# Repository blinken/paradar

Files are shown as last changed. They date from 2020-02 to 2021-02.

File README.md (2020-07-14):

# paradar: locates and indicates aircraft around you

<div align="center">
<br/>
<br/>
<br/>
<br/>
<del>£339</del> <b>£299 <a href="https://paradar.co.uk">Click here to buy a paradar!</a> All sales help fund development.</b><br/>
<br/><br/>
</div>

### paradar is a tiny, handheld ADS-B receiver for paramotor, paraglider, drone and general aviation pilots.

 * 36 ultrabright LEDs clearly indicate the direction of other aircraft in a ~20km radius
 * Fully self contained handheld receiver and display - can be used without a linked phone or tablet
 * Much faster to understand at glance vs an app on your phone
 * Optionally feeds high quality GPS and traffic information to SkyDemon or other GDL90-compatible EFB apps
 * Easily readable in full sunlight, on the ground or in the air on your flight deck
 * Receives ADS-B on 1090Mhz (UK/EU) and 978Mhz (US)
 * Colour-blind-friendly colours
 * Built-in 1950mAh battery (2.5 hours battery life) with USB-C fast charge
 * Only 88mm x 88mm and 175g with antenna
 * **Open source hardware and software**

It can be used standalone (with or without a phone or tablet), on the ground as
a handheld compass that indicates air traffic, or in the air on your flight
deck to improve your situational awareness.

Paradar is the result of a short two-week project that grew into a monster. I
fly in a busy area, and I wanted to see aircraft in the sky around me - and
apps designed for fixed-wing pilots are tricky to read while flying
an ultralight. Paradar started out as a Raspberry Pi attached to a USB
software-defined radio dongle, and some LEDs from Amazon. Six months later,
it's now a professionally manufactured PCB and case that fits in the palm of
your hand. The journey to get here was [long and arduous.](#design)

<div align="center">
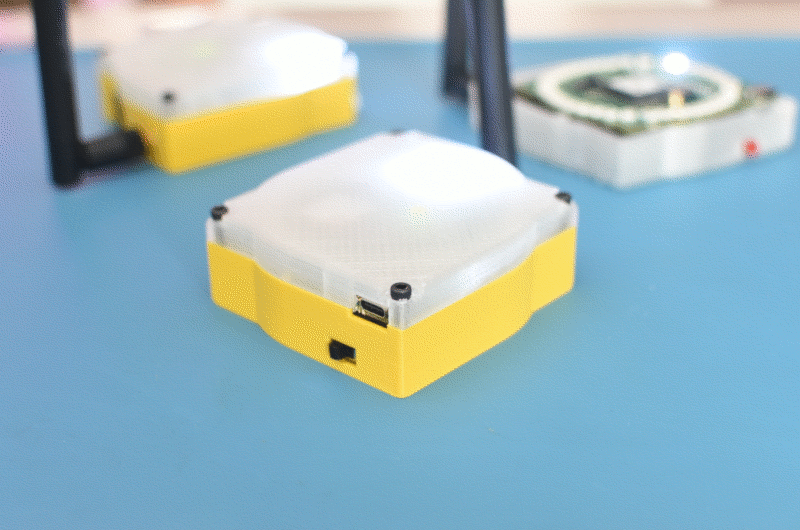
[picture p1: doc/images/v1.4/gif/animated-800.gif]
<br/>
<i>Check out the cool animated GIF I made</i>
</div>

# Project news & roadmap

### Hardware

**2020-05-03** Not too much to report recently: I'm mostly waiting for
manufactured PCBs from PCBWay to arrive. They're making progress, which is
good - but COVID-19 is causing huge delays. Assembled boards should ship soon -
then I get to do a ton of testing!

**2020-03-29** A lot of work this week to finalise assembly, fix bugs after
feedback from the beta testers, and start the process of finding someone I can
outsource the PCB manufacture to. To put together the first few boards I'm
working with [PCBWay](https://www.pcbway.com/pcb-service.html) (click for some
neat videos) in Shenzhen, China, who are a large PCB manufacturer and assembler - alongside
a distributor in the UK to sell and source the devices. It's been a pretty
straightforward experience working with them so far - most of the pain has been
around sourcing parts, but we've settled on a final BOM that they say they can
deliver.

Obviously the massive global disruption from COVID-19 is causing a few
headaches, mostly around shipping and delivery of parts - getting certain
microUSB connectors has been a nightmare. However, the cursed package arrived
this week (the final component I was waiting on) and now it's possible to
assemble the boards together in one unit.

The bottom photo below is of the new optimised assembly. For the beta units, we
soldered wires by hand from the USB port to the Raspberry Pi (top photo) - and now
there's a neat little custom adapter board to do this!

<p align="center">
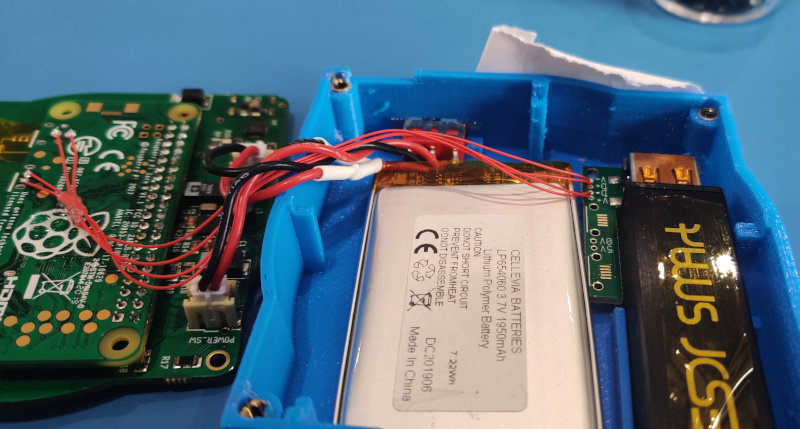
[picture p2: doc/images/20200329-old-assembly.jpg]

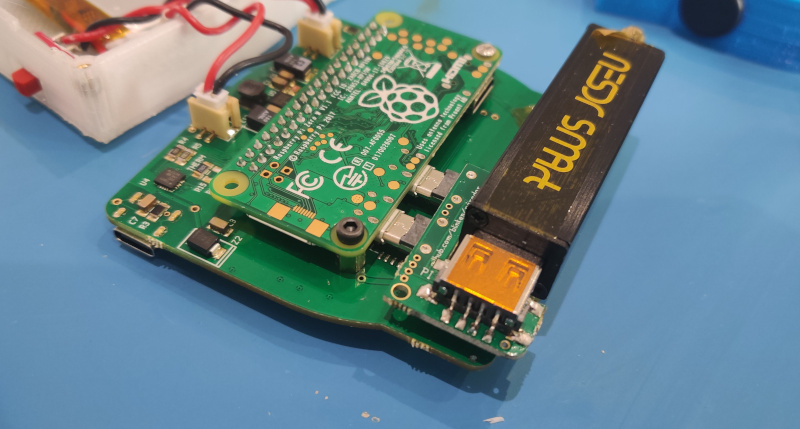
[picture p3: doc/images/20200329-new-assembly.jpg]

</p>

Some other news - paradar branded antennas! 1090Mhz antennas are really hard to
get at a reasonable price outside of a manufacturer - they're fairly specialist -
and manufacturers won't sell you less than a few hundred. So we've found a
factory and ordered a _load_. But as a bonus, they'll engrave a logo!
Behold the new paradar logo and antenna design:

<p align="center">
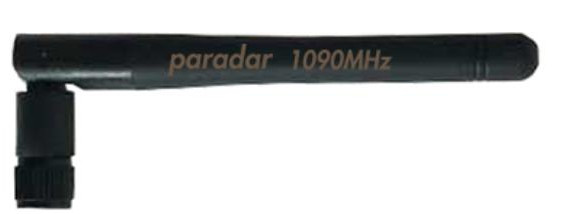
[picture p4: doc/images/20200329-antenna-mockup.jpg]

</p>

**2020-03-24** Coronavirus disruption aside... my [distribution partner](https://paradar.co.uk) in the
UK is shipping the first run of Paradars! I have a small number ready to go,
and enough components to make up a few more around the ongoing supply chain
disruption. Get them while they're hot!

**2020-02-25** DHL confirms that the first run of boards has _arrived in the
UK!_ With luck, they'll be with my distrubution partner by the end of the week.
Assuming there's no unexpected hardware issues, there should then be enough
boards and components to make up the set of 10 units for the beta test group
over the weekend.

Case design has also been ticking along, and my ghetto towel-covered 3D printer
has been working overtime to print up prototypes. So many broken prototypes. 3D
design is hard. The good news is that I've settled on a case that
encapsulates a larger but less-power-hungry SDR, featuring a sturdier SMA
connector. It's a touch larger overall but worth it from a reliability perspective.

<p align="center">
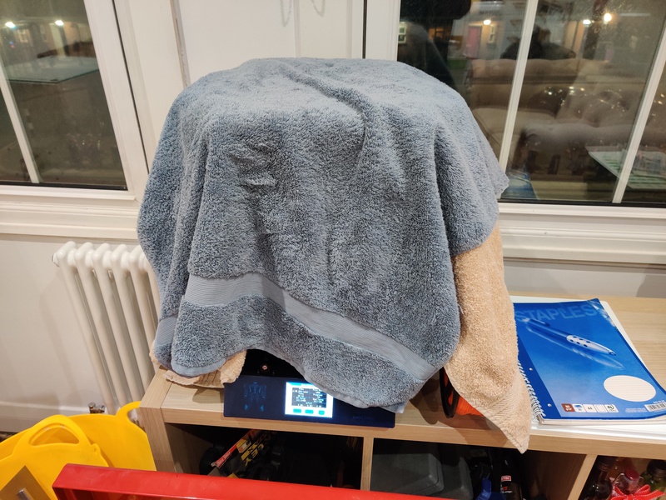
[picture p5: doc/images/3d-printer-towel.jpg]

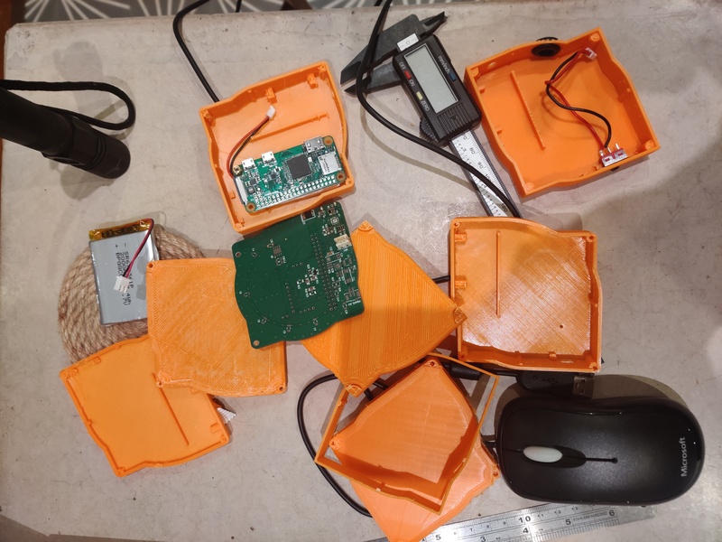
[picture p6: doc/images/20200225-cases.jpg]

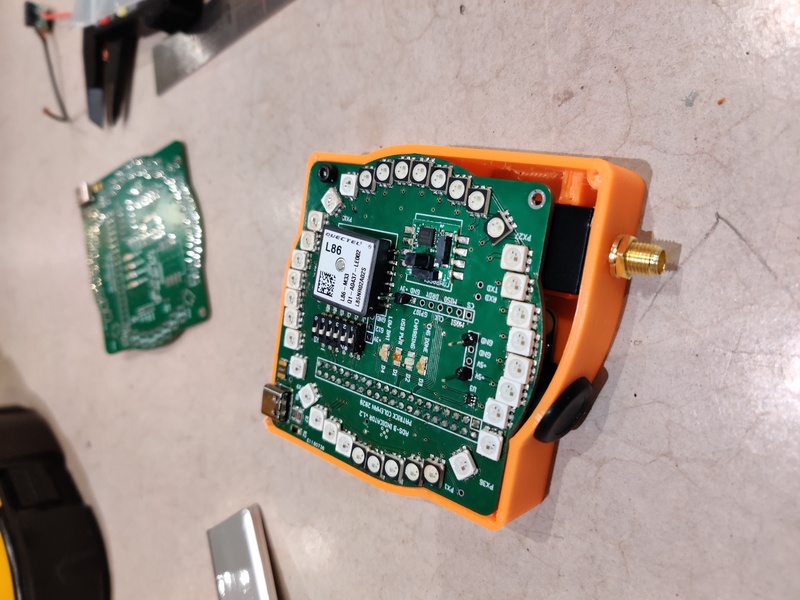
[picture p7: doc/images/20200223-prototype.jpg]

</p>

The next step is to print some cases in transparent ABS to verify the LEDs can
be clearly seen. Not much left to do here!

**2020-02-12** After (too) many iterations, the final, tested PCB layout is
done :tada: :tada: and has been sent for an initial manufacturing run of 40
boards.

The case design is close to complete, but requires some tweaking to add holes
for the SD card and antenna.

### Software

**2020-03-24** Some good bugfixes this week from *loads* of testing.

 * Fix an off-by-one error that meant the 36th LED wasn't getting used
 * Improve compass stability a ton - by adding a moving average over the sensor readings
 * Improve wifi reliability (fix GPIO pullup issues)
 * Improve SkyDemon compatibility - send messages slightly more often

Battery life tests out at 2-2.5 hours without wifi, which is probably as good
as we're going to get without a bigger battery. That SDR is pretty power
hungry.

**2020-03-24** Software is complete and well-tested. Test units have been shipped to a small group of beta testers for their feedback

**2020-02-25** We're just about feature-complete! 978MHz ADS-B is working, LED
colours are now red/green-colourblind-friendly, take-me-home feature is
implemented and working. The user can configure the following features via the
six configuration switches on the top of the board:
 * high_brightness: switch LEDs between medium and high brightness
 * wifi_enabled: enable/disable Wifi AP mode (for SkyDemon) - to be implemented
 * track_home: enable/disable recording GPS location at startup (or when switch is activated), and indicate the direction with a light blue LED.
 * show_north: enable/disable indication of compass north as a white LED on the display
 * led_test: enable/disable test mode, which cycles through red/green/blue/white to help with manufacturing (spotting dead LEDs)
 * enable_978: enable/disable 978MHz reception. The device only has one radio,
   so when this mode is enabled it will listen for about 10 seconds at a time
   on each frequency. Aircraft broadcast their position every 1-2 seconds, so
   there's a low probability that any will be missed. This is only useful in
   the USA, where 978MHz is in use.

The main remaining feature here is GDL90/SkyDemon support and testing. It's
really exciting to be so close to the finish line!

**2020-02-12** The software supports receiving ADS-B on 1090Mhz (EU frequency),
indicating it on the display, and mapping the display to the user's position
using the compass. The following extra features are planned for the initial
release in April/May:

 * WiFi base station and support for SkyDemon via GDL90
 * Support for US ADS-B (978MHz)
 * A ton of Ansible automation to ensure the board runs reliably
	 * Take a Raspbian image and deploy the software to it
	 * Convert an SD card between read-only and read-write mode
	 * Start software on boot
	 * Watchdog to ensure software is running correctly
 * User configuration via the DIP switches on the board
	 * WiFi on/off to save battery
	 * Listen on 1090Mhz, 978Mhz, or both (switch between frequencies periodically)
	 * LED brightness

# Design

<p align="center">
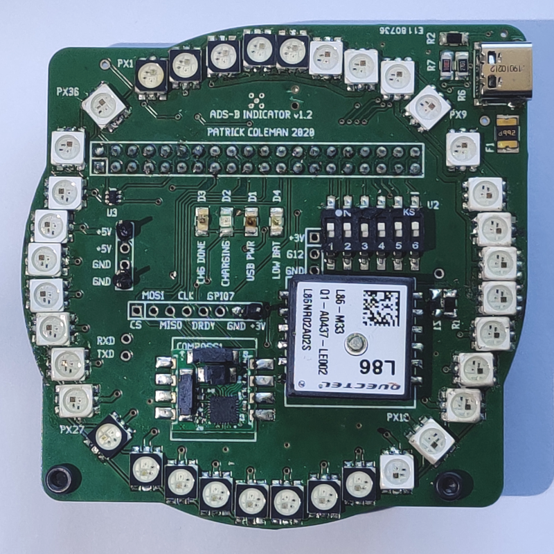
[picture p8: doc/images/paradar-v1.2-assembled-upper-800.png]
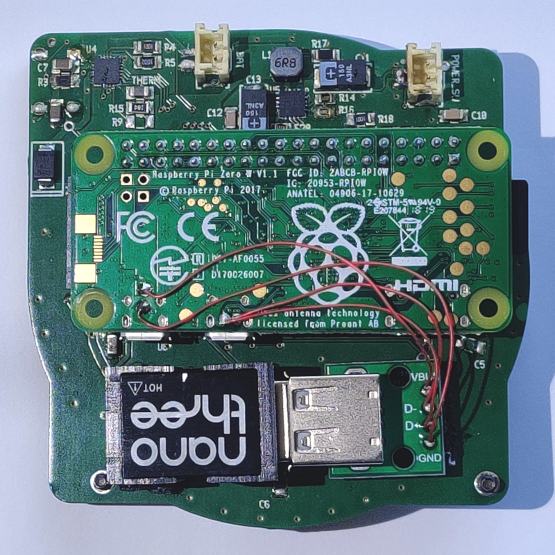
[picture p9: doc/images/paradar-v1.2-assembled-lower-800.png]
 <br/>
<i>Board version v1.2 without the USB right-angle connector</i>
</p>

paradar is built around the Raspberry Pi Zero, a cheap and fast general purpose
embedded computer (1GHz ARM, 512MB RAM) with built-in WiFi. The software runs
on an SD card booting Linux (based on Raspbian), which provides drivers for the
SDR and supporting software.

| Part | Where to buy  |
|:---| ---:|
| Raspberry Pi Zero W | [Adafruit](https://www.adafruit.com/product/3400), [Pi Supply](https://uk.pi-supply.com/products/raspberry-pi-zero-w) |
| paradar main PCB | [Order on PCBway](https://www.pcbway.com/project/shareproject/paradar__a_portable__handheld_ADS_B_indicator_and_receiver.html), or [shoot me an email](mailto:blinken@gmail.com) |
| paradar USB adapter PCB (fits the SDR neatly next to the Pi Zero)  | [Order on PCBway](https://www.pcbway.com/project/shareproject/Raspverry_Pi_Zero_USB_right_angle_adapter.html), or [shoot me an email](mailto:blinken@gmail.com) |
| Nooelec NESDR SMArt v4 SDR | [Amazon](https://www.amazon.co.uk/Nooelec-NESDR-SMArt-SDR-R820T2-Based/dp/B01HA642SW), [Nooelec](https://www.nooelec.com/store/sdr/sdr-receivers/nesdr/nesdr-smart-sdr.html) |
| 2x20 2.54mm header  | [RS](https://uk.rs-online.com/web/p/pcb-headers/8281563/), [Amazon](https://www.amazon.co.uk/William-Lee-2-54mm-Break-away-Header-Raspberry/dp/B07TK1CLCZ/) and many other suppliers |
| Battery | [RS](https://uk.rs-online.com/mobile/p/family-id/1251266/), [TME](https://www.tme.eu/en/details/accu-lp654060_cl/rechargeable-batteries/cellevia-batteries/) |
| Power switch | [RS](https://uk.rs-online.com/web/p/slide-switches/7347328/) |
| 3D-printed case | [Design files](https://github.com/blinken/paradar/tree/master/case) |

The major SMD components are the PNI RM3100 high-resolution compass module, Quectel L86 GPS, and 36x WS2813 LEDs.

## Main PCB / Pi shield

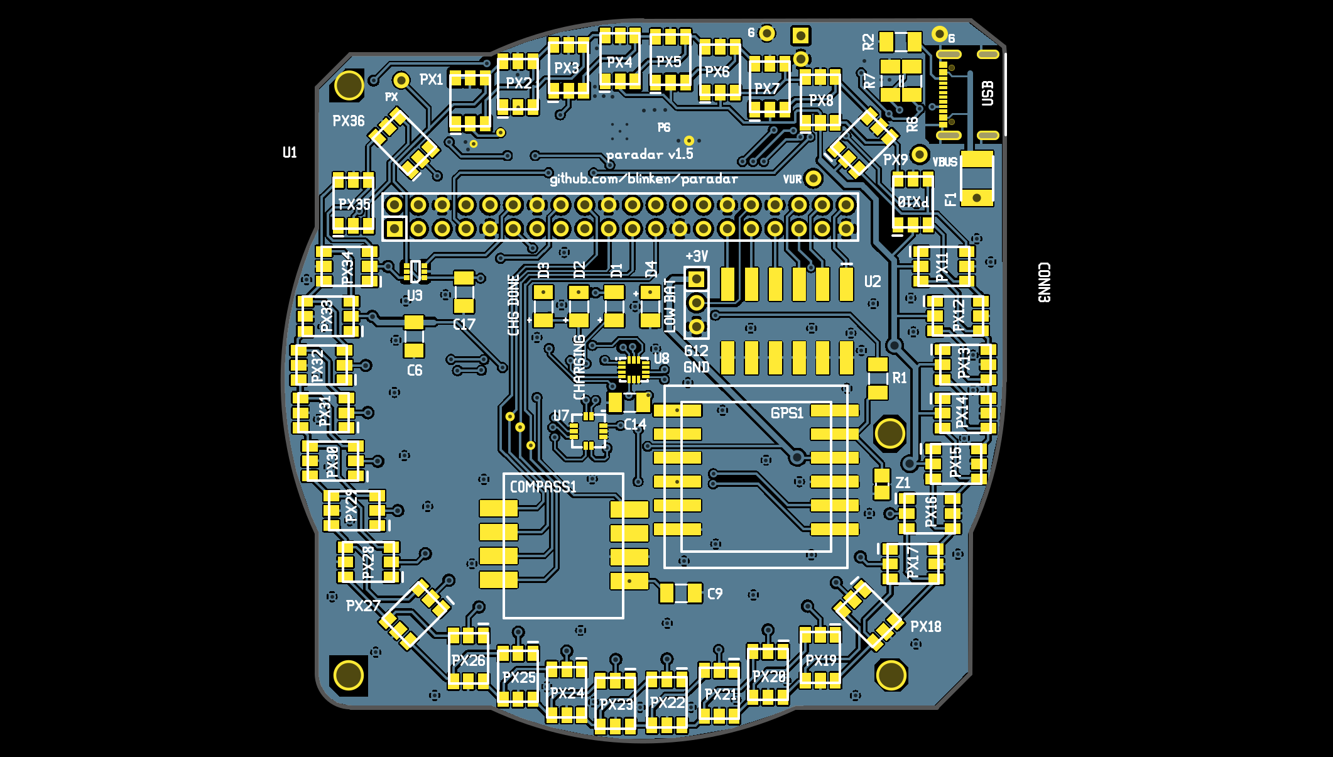
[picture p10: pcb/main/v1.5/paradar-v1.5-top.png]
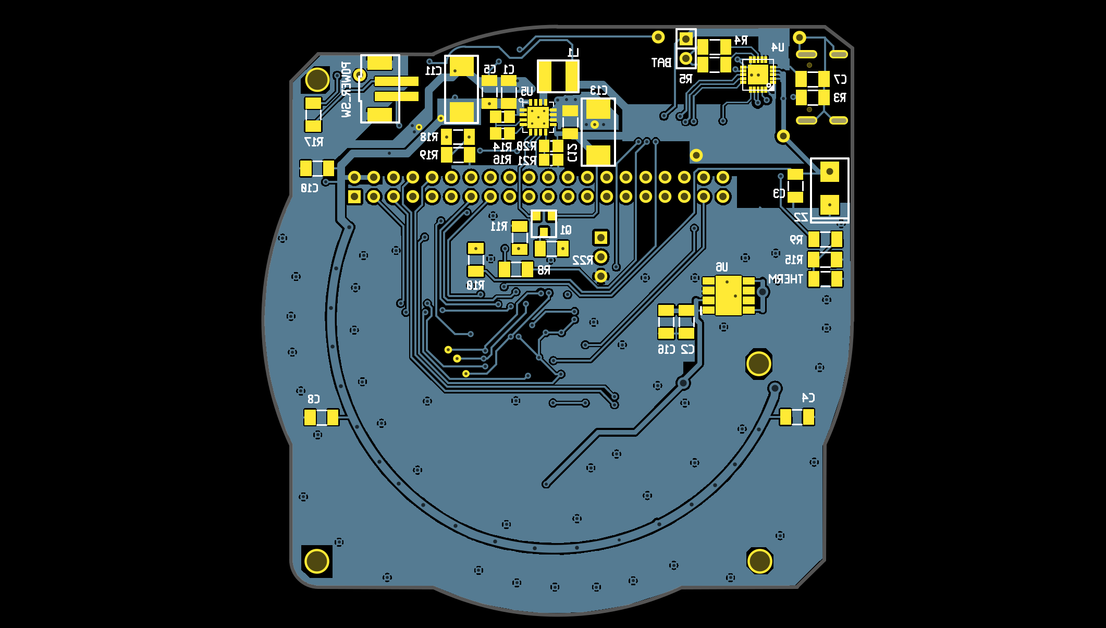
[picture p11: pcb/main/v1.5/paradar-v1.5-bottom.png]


 * [v1.5 gerbers](https://github.com/blinken/paradar/raw/master/pcb/main/v1.5/paradar-v1.5.zip)
 * [v1.5 schematic](https://github.com/blinken/paradar/raw/master/pcb/main/v1.5/paradar-v1.5-schematic.pdf)
 * [v1.5 BOM](https://github.com/blinken/paradar/raw/master/pcb/main/v1.5/20200325-paradar-v1.5-pcbway-bom.xlsx)

The concept here is pretty simple - securely connect a compass, GPS and LED
ring (and in version 1.5, a pressure sensor and accelerometer) to the Raspberry
Pi. The board incorporates:

 * PNI RM3100 high-resolution compass module. Works well in environments with lots of electrical noise.
 * Quectel L86 GPS module with integrated antenna. GPS backup power is supplied from the main battery (speeds up GPS startup time)
 * A ring of WS2813 programmable LEDs. These are very, very bright (2300mcd white, 480mcd red) and all LEDs can be easily controlled with one GPIO pin.
 * 6-way DIP switch connected to Pi GPIO pins, to allow the user to configure the device in the field.
 * USB-C power supply with TPS61090 boost converter and MCP73871 LiPo battery charger. Allows powering the unit via USB-C @ 5V/2A (with the battery providing for load spikes if necessary), battery charging, and powering direct from battery. The TPS61090 handles the boost of battery voltage (~3V) to the 5V required by the Raspberry Pi. Includes a resettable fuse and a TVS diode to absorb voltage spikes on the USB line.
 * LEDs to indicate USB power connected, charging, charge done, low battery.
 * A 500mA LDO regulator supplies 3.3V to the compass and GPS (not connected to the Raspberry Pi 3.3V power supply)
 * A pad for a JST 6-GH connector is incorporated on the bottom of the board to permit future support of a FLARM Atom.
 * A variety of jumpers exposing GPIOs, power lines, serial & SPI to allow future expansion.
 * Mounting holes to suit an undermounted Pi 3 A+ or Pi Zero.

**The first mockup featured a few components from Amazon velcroed to a plastic
lid.** I figured I'd get a PCB made to make things nicer. Then scope creep and
silly mistakes crept in... and five board revisions later there's 36 LEDs and a
switchmode power supply with QFN20 ICs. I got the SPI MISO/MOSI pins for the
compass backwards *no less than three times*.

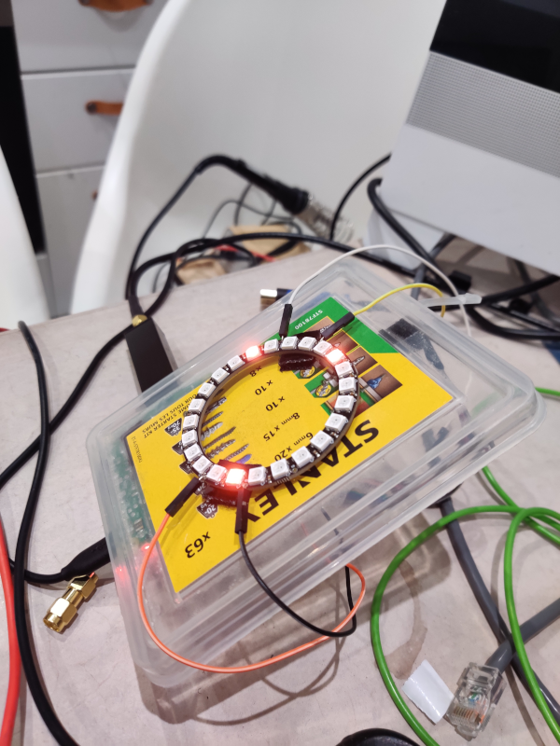
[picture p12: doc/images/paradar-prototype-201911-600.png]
<div align="center"><br/>
The first iteration of the design consisted of a plastic lid velcroed to a Raspberry Pi.
</div>

### Boost converter hell

The original design used an off-board modular power supply; I decided I wanted
to incorporate it onto the main PCB, to reduce weight and size. My friends all
told me that switchmode design was hard (as if I was going to listen to that).
I threw a design together based loosely on the Adafruit PowerBoost and sent it
off to be manufactured. Without bothering to test it first.

Hubris caught up with me: it turns out, board layout matters. In board version
1.3, the ground return from the negative terminal of the output capacitor had a
poor connection to the power ground on the boost converter. As a result,
sometimes the boost converter would work perfectly: and sometimes it would fry
the IC's internal MOSFET after an hour or so. The dead boost converter would short
battery voltage to ground, which made things even more sad (read: toasty).
_Dear TI: this is an incredibly unhelpful failure mode._

I spent weeks debugging this problem, because it presented as a short on the 5V
bus that only appeared after some time in operation, about 50% of the time. I
was so desperate I considered buying a FLIR camera to look at current flows to
locate the problem.  But careful deduction and my hot air rework station saved
the day (desoldering components one by one until the short went away), and I
was then able to show that a wire soldered between the two problematic
components reduced the failure rate (though not to zero). In one evening I
replaced and then instantly fried 9 boost converters on the same board. They
cost $3 each. It hurt.

As a result, board v1.4 features a redesigned boost converter layout. There's
some compromises (ground return is across the other side of the board), but I
was unwilling to change too much at the risk of introducing another bug. It
works so well and I am so happy.

<div align="center">
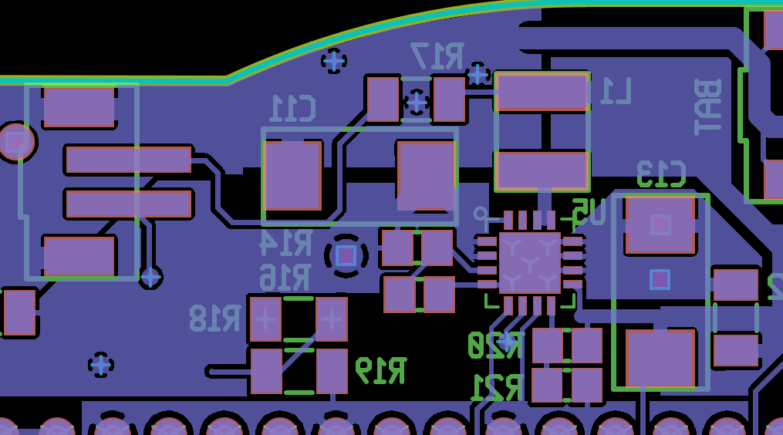
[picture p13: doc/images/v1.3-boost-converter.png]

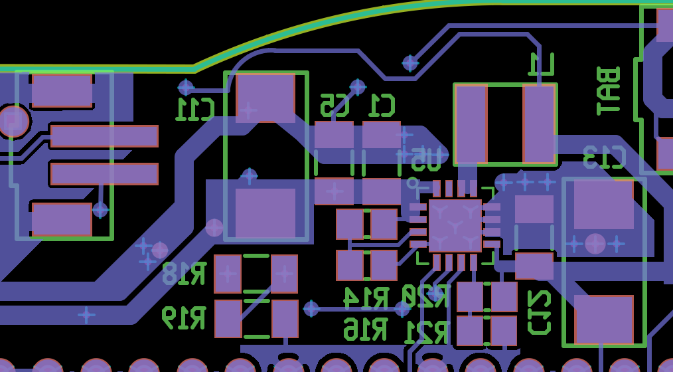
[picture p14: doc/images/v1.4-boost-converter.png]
<br/>
v1.3 boost converter design (left) compared with v1.4. The ground path back to
the boost converter is now via the other side of the board: this isn't ideal
from a noise perspective, but there weren't easier solutions without a larger
redesign.
<br/>
<br/>
</div>

tl;dr - boost converters are REALLY HARD THEY WILL DRIVE YOU INSANE >:{

### Other learnings

 * Sourcing components in the middle of a global pandemic is hard.
 * Testing a device that detects aircraft - when there are no aircraft flying due to aforementioned pandemic - is also hard.
 * Soldering a WS2813 LED sideways shorts +5V to ground, and turns the LED
   power trace into a resistive heater. A board at 200 degrees Celcius for an
   hour effectively liquifies a PETg plastic case (on the upside, the power supply worked great)
 * Designing against components commonly available from RS in the UK means that
   assembly in China will be a challenge :'(
 * Soldering USB-C connectors using anything at home is a nightmare. I tried
   two manufacturers and still can't get soldering reliable, using a stainless
   steel stencil and an oven. I gave up and outsourced manufacturing.
 * Scope creep

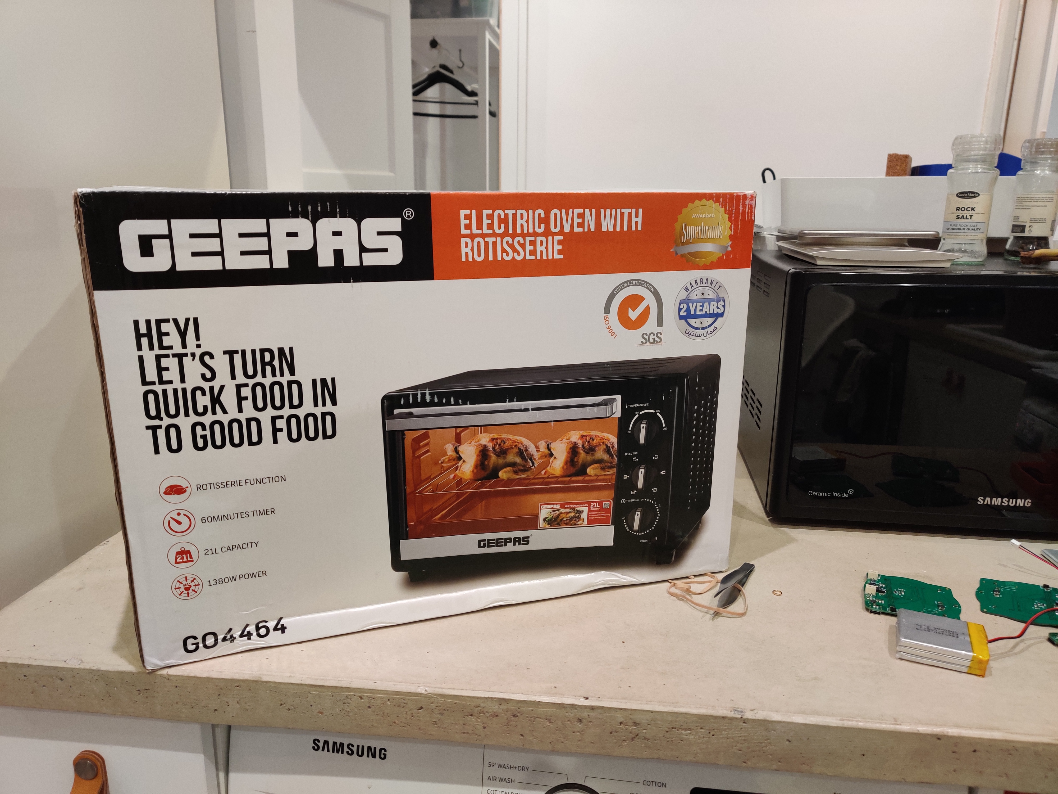
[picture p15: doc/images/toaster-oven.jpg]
<p align="center"><br/>
Wonder what this is for? Hint, not chicken</p>

## USB adapter PCB

<p align="center">
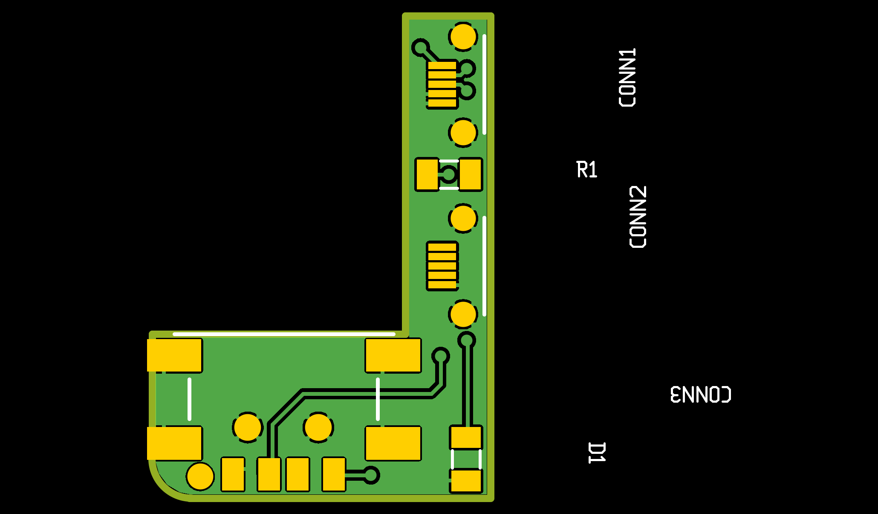
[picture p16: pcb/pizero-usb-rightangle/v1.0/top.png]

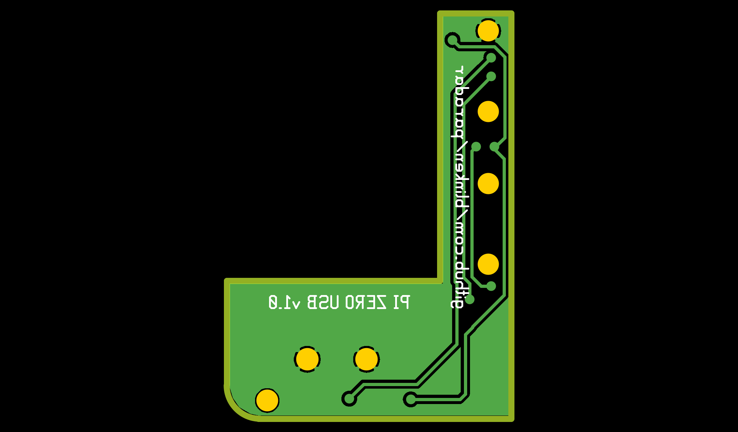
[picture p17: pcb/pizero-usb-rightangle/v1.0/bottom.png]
<br/>

</p>

 * [v1.2b gerbers and board renders](https://github.com/blinken/paradar/tree/master/pcb/pizero-usb-rightangle/v1.2b-panelised)

To get a more compact case, the USB connection needs to make a sharp
right-hand bend so the SDR can sit neatly alongside the Pi. Does anyone make a
tight right-hand USB adapter? Of course not; people want pink android-shaped
USB adapters. And the market [provides](https://www.amazon.co.uk/gp/product/B07F94DS6X). 
So this board connects to both Pi Zero microUSB ports and exposes a compact USB
A socket for the SDR.

The Pi Zero's power input port (the one closer to the edge of the board) is not
connected - it's just used for mechanical support. The Pi is powered via the
GPIO pins connected to the main PCB.

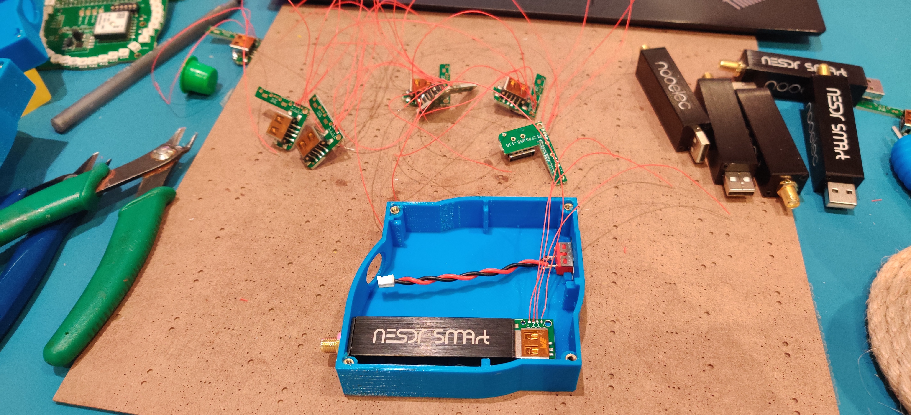
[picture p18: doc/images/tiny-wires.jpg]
<p align="center"><br/>
Manually soldering tiny wires. So many tiny wires. Don't do this.</p>

## Case

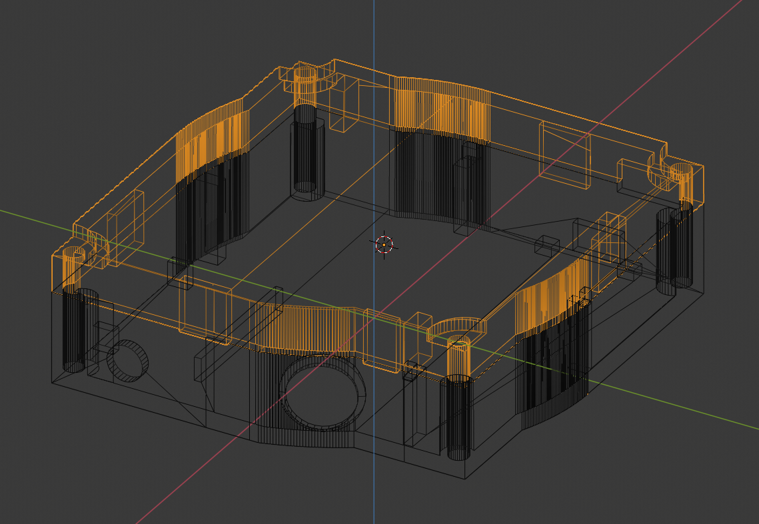
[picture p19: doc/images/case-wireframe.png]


The case is 3D printed and follows the shape of the board. It incorporates a
hole to permit easy removal of the SD card (filled with a [rubber grommet](https://www.amazon.co.uk/Metric-Rubber-Closed-Blanking-Grommets/dp/B07P73Z7KK)),
slot for the power switch, and a hole for the antenna connector off the SDR.
The lid has holes for [M3 hex screws](https://uk.rs-online.com/web/p/socket-screws/4679818/),
and the base 4mm shafts to hold [brass inserts](https://uk.farnell.com/tr-fastenings/m3-uhbrxpsf/brass-insert-unheaded-m3/dp/2474926) for the M3 threads.

I learned how to use Blender to make this. I use the word "learned" loosely.

Dimensions without antenna are 88 x 88 x 30mm. The antenna connector is
SMA, and the included antenna is 110mm in length with a flexible elbow.

Both bottom and lid are 3D-printed in PETg (the lid is translucent). This is
resistant to most solvents and fuels, though the case is not waterproof. Maybe
in a future version (scope creep!).

The case was arrived at after a lot of iterations. Obviously I justified (I use
the word "justified" loosely) buying a 3D printer for this project (my trusty
Anycubic Mega-S) and it churned out prototypes, and was a gamechanger in terms
of rapid iteration.

The current version of the case features posts to support the switch and
support the PCB, plus posts in the lid to hold the PCB down (so it's sandwiched
in a fixed position). The SDR (which gets hot) is kept separated from the battery by
a small tab. The lid locks to the base to permit easy assembly, and there's a
hole to give access to the SD card to permit firmware upgrades in the field.

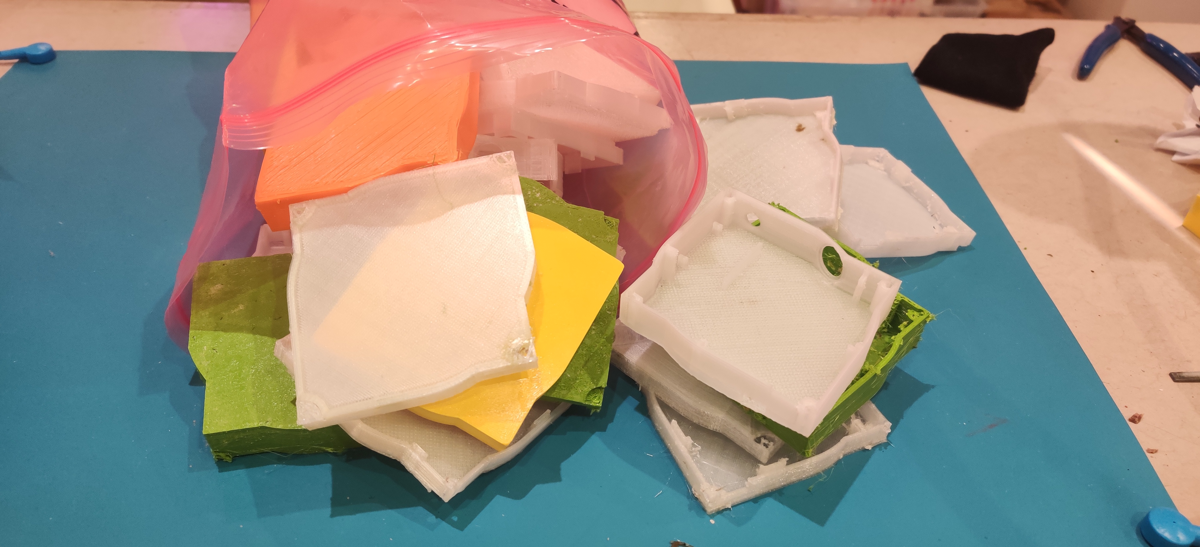
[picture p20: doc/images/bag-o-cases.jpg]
<p align="center"><br/>
It took a lot of iteration to get here.</p>

# Support, bug reports, and feedback

I'm still in really early stages here, and if you have thoughts (particularly
if you fly fixed-wing aircraft, ultralights, or drones) I'd love to hear your thoughts.
[Shoot me an email](mailto:blinken@gmail.com), or [raise an issue on
GitHub](https://github.com/blinken/paradar/issues).

You can find the user manual [here](https://github.com/blinken/paradar/blob/master/doc/user-manual.md).

# Buy a paradar

[Click here to buy one!](https://paradar.co.uk)

**Please read the disclaimer and license section below. By purchasing paradar,
you are indicating that you have read and agree to the disclaimer and
license.**

I don't sell or distribute these devices - I only maintain the open source
project. [paradar.co.uk](https://paradar.co.uk) manufactures paradar units,
comes recommended by me, and you can grab one on their website! Discounts are
available for volume purchases.

# Disclaimer and license

**paradar does not replace your responsibility to look for, see and avoid other
aircraft. This device will not save your life. It is intended only to provide
additional situational awareness of some traffic around you when flying VFR. It
is not designed for and must not be used for IFR flight, and you must not rely
on it when flying in any conditions.**

**The pilot is responsible for the safe conduct of any flight, and for obeying
all applicable laws.**

    Copyright (C) 2020 Patrick Coleman
    
    paradar is free software; you can redistribute it and/or modify
    it under the terms of the GNU General Public License as published by
    the Free Software Foundation; either version 3 of the License, or
    (at your option) any later version.
    
    paradar is distributed in the hope that it will be useful,
    but WITHOUT ANY WARRANTY; without even the implied warranty of
    MERCHANTABILITY or FITNESS FOR A PARTICULAR PURPOSE.  See the
    GNU General Public License for more details.
    
    You should have received a copy of the GNU General Public License along
    with this program; if not, write to the Free Software Foundation, Inc.,
    51 Franklin Street, Fifth Floor, Boston, MA 02110-1301 USA.

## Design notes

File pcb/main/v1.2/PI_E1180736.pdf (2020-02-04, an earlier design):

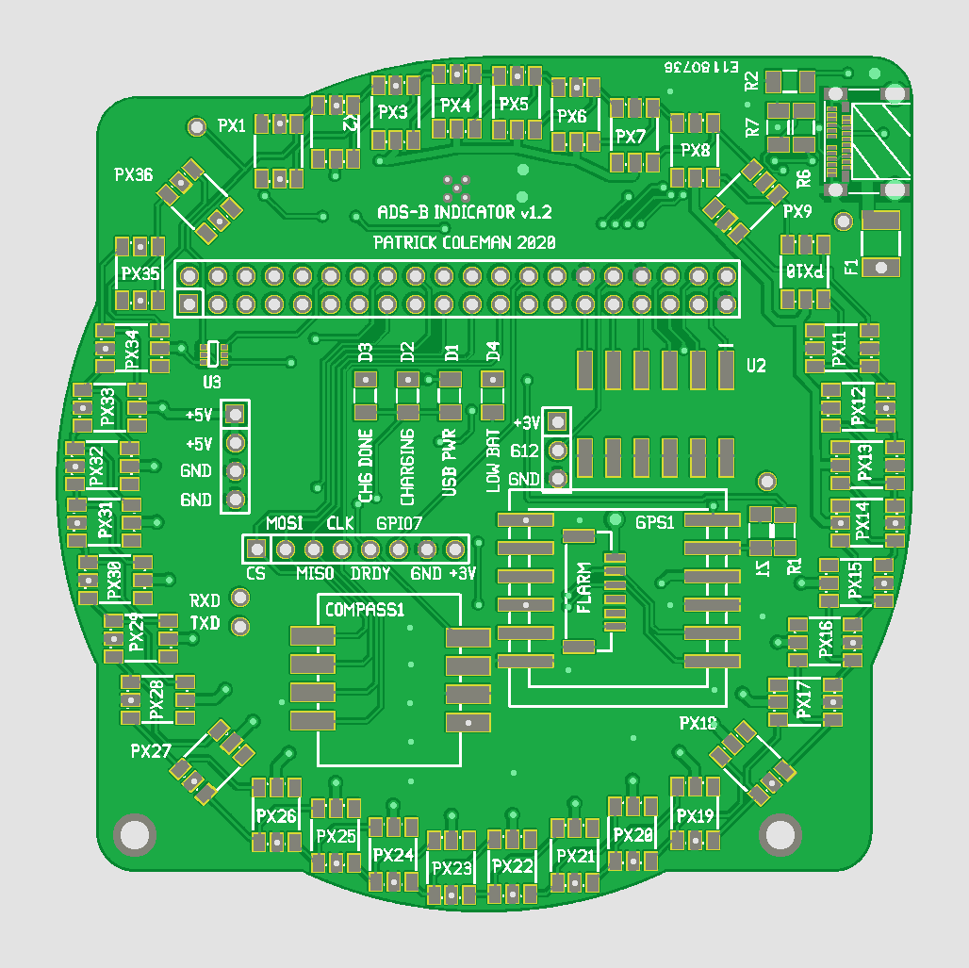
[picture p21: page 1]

E1180736 PCB view TOP (topview)

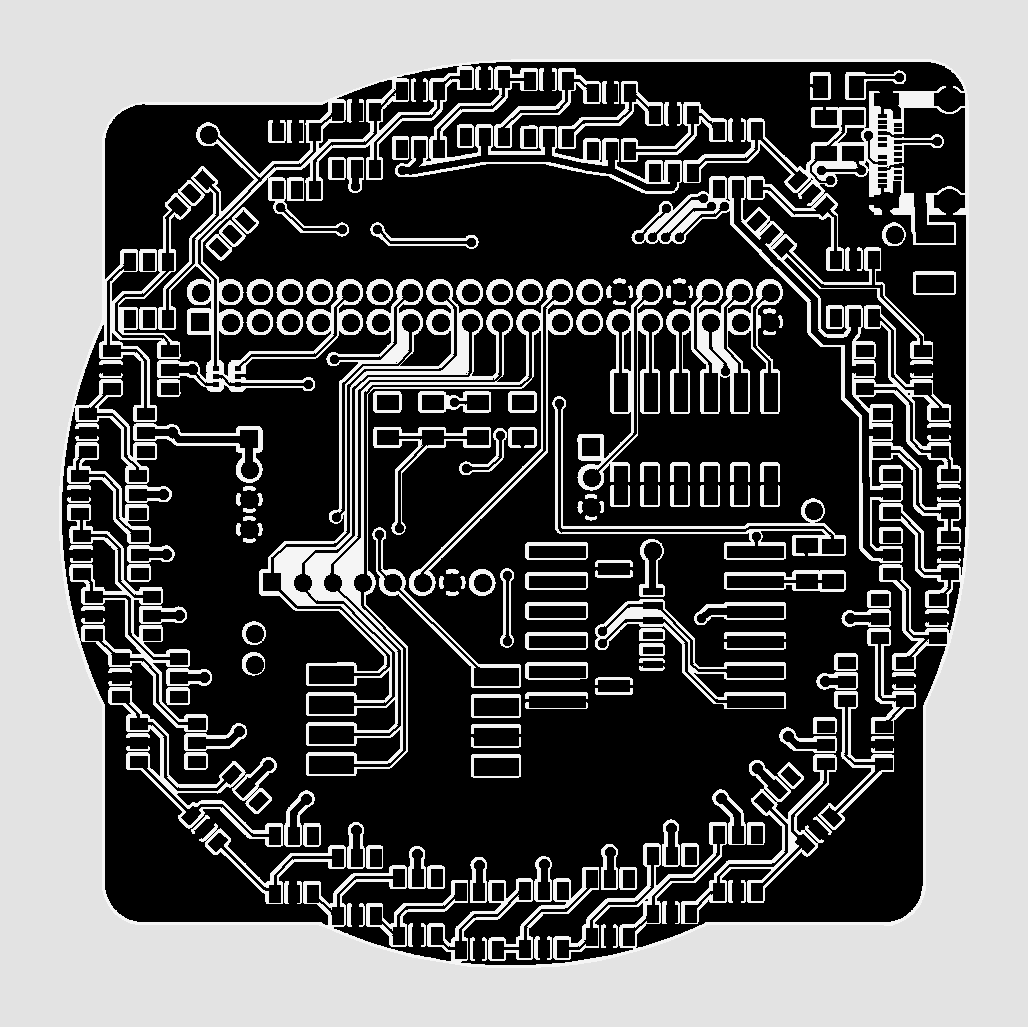
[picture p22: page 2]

E1180736 TOP layer Image (topview)

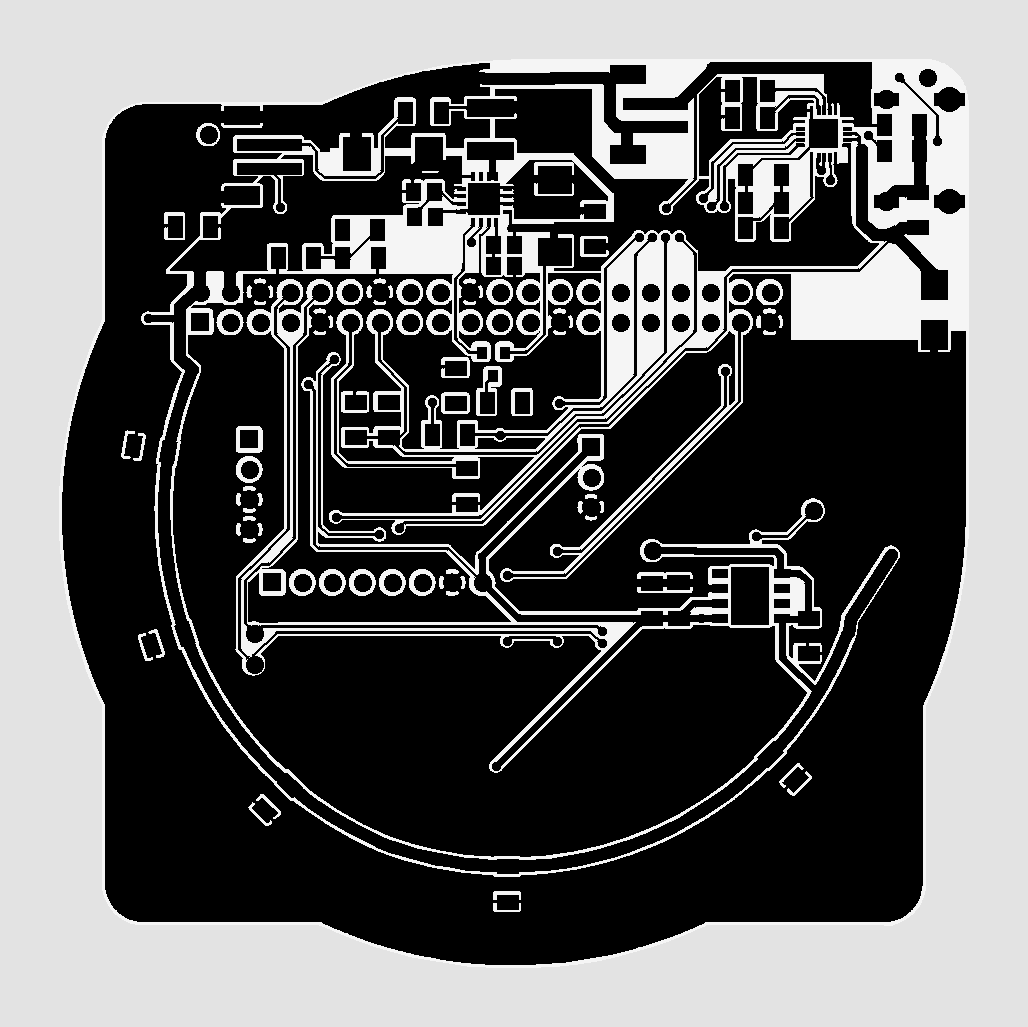
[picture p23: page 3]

E1180736 BOTTOM layer Image (topview)

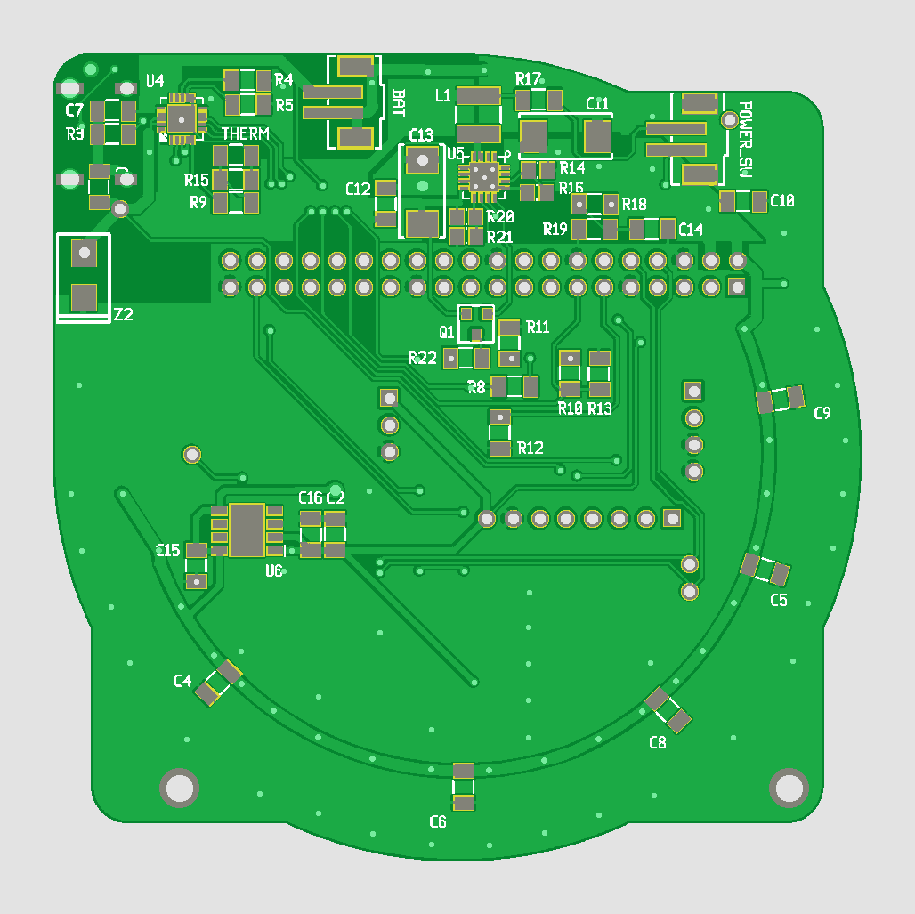
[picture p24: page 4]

E1180736 PCB view BOTTOM (bottomview)

# E1180736 PCB Mechanical view (topview)

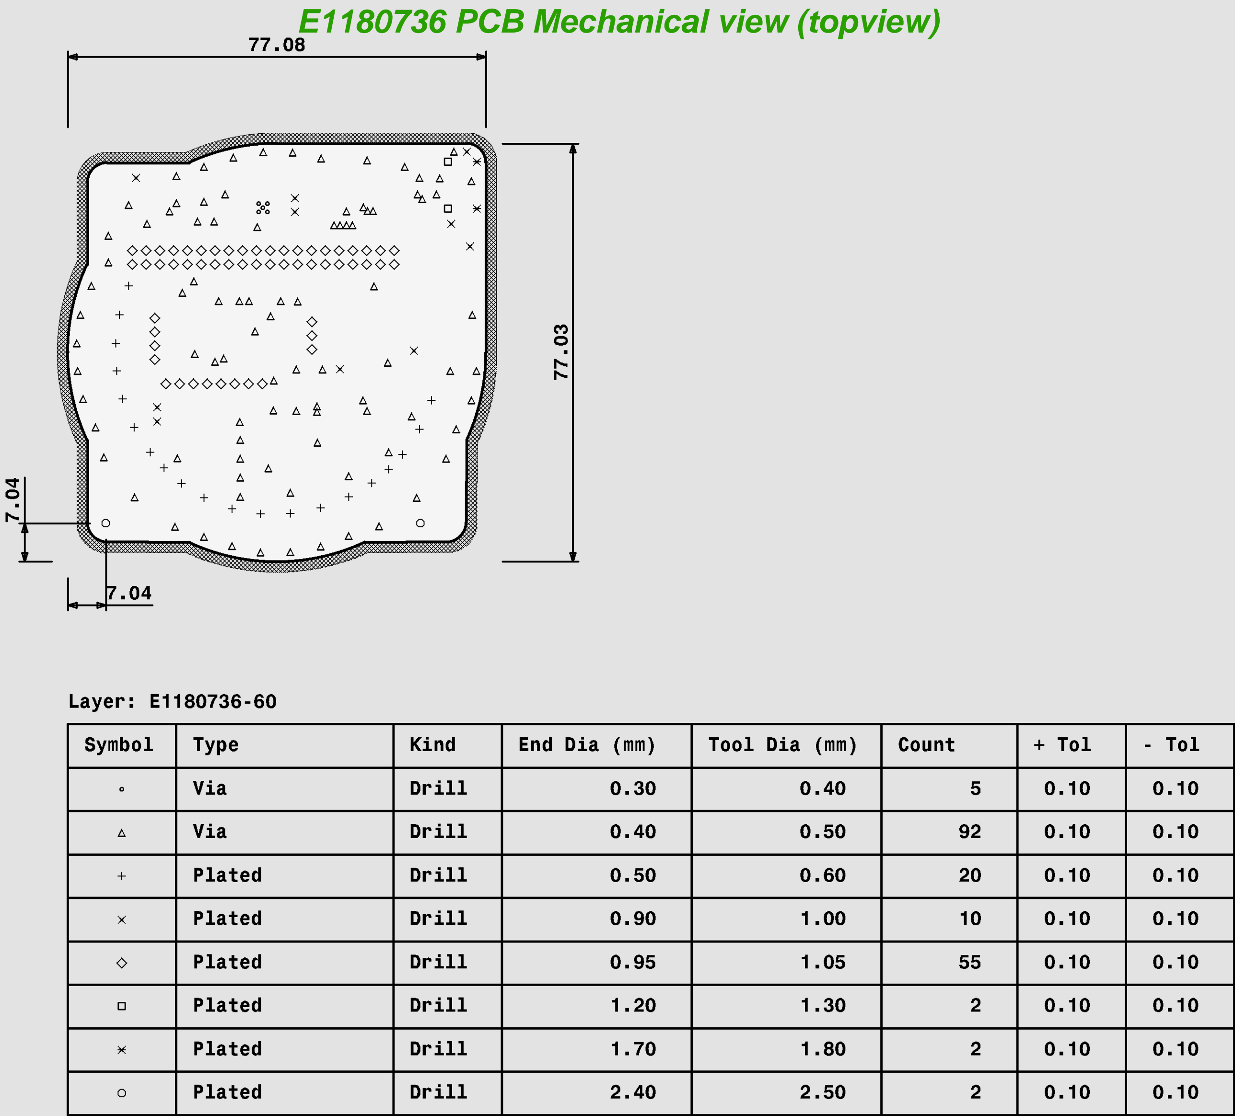
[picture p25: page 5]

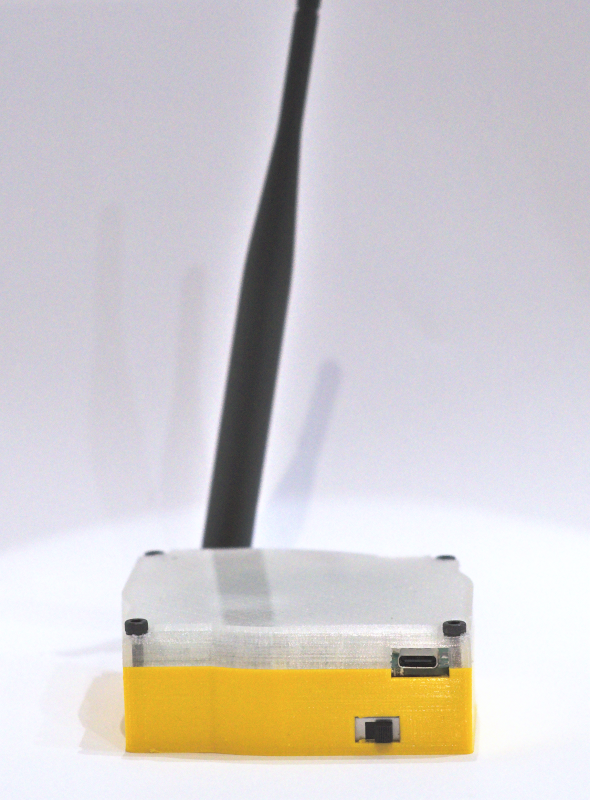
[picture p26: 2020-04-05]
doc/images/20200324-yellow-case-800.png

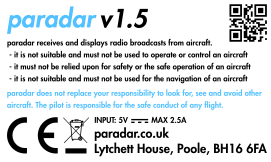
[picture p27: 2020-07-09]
doc/ce-label.png

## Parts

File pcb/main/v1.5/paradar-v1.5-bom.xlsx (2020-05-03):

Item # | *Ref Des | *Qty | Manufacturer | *Mfg Part # | Description / Value | *Package | Type | DigiKey part number | Your Instructions / Notes
1 | C9. | 1 |  |  | 0.1uF | 1206 | CAPACITOR |  | Please supply quality generic ceramic 5%
1 | C2. | 1 |  |  | 0.1uF | 1206 | CAPACITOR |  | Please supply quality generic ceramic 5%
1 | C14. | 1 |  |  | 0.1uF | 1206 | CAPACITOR |  | Please supply quality generic ceramic 5%
1 | C17. | 1 |  |  | 0.1uF | 1206 | CAPACITOR |  | Please supply quality generic ceramic 5%
2 | C1. | 1 |  |  | 47uF | 1206 | CAPACITOR |  | Please supply quality generic ceramic 5%
2 | C3. | 1 |  |  | 47uF | 1206 | CAPACITOR |  | Please supply quality generic ceramic 5%
2 | C4. | 1 |  |  | 47uF | 1206 | CAPACITOR |  | Please supply quality generic ceramic 5%
2 | C5. | 1 |  |  | 47uF | 1206 | CAPACITOR |  | Please supply quality generic ceramic 5%
2 | C6. | 1 |  |  | 47uF | 1206 | CAPACITOR |  | Please supply quality generic ceramic 5%
2 | C7. | 1 |  |  | 47uF | 1206 | CAPACITOR |  | Please supply quality generic ceramic 5%
2 | C8. | 1 |  |  | 47uF | 1206 | CAPACITOR |  | Please supply quality generic ceramic 5%
2 | C12. | 1 |  |  | 47uF | 1206 | CAPACITOR |  | Please supply quality generic ceramic 5%
2 | C10. | 1 |  |  | 47uF | 1206 | CAPACITOR |  | Please supply quality generic ceramic 5%
2 | C16. | 1 |  |  | 47uF | 1206 | CAPACITOR |  | Please supply quality generic ceramic 5%
3 | C11. | 1 | Panasonic | 10TPB150ML | 150uF 10V | TPB-D3L | CAPACITOR | P16446CT-ND
3 | C13. | 1 | Panasonic | 10TPB150ML | 150uF 10V | TPB-D3L | CAPACITOR | P16446CT-ND
4 | D1 | 1 | Kingbright | KPTD-3216CGCK | Green | 1206 | LED |  | Can substitute any 1206 2.1V Green LED
4 | D3 | 1 | Kingbright | KPTD-3216CGCK | Green | 1206 | LED |  | Can substitute any 1206 2.1V Green LED
5 | D2 | 1 | Kingbright | KPTD-3216SYC | Yellow | 1206 | LED |  | Kitted/consigned (customer will supply)
6 | D4 | 1 | Kingbright | KPTD-3216SRC-PRV | Red | 1206 | LED |  | Can substitute any 1206 2.1V Red LED
7 | F1. | 1 | Bourns | MF-MSMF260-2 | Resettable fuse 2.6A trip 5.2A @ 5s | MF-MSMF260-2 | FUSE | MF-MSMF260-2CT-ND | 2.6A / TRIP 5.2A @ 5s
8 | L1. | 1 | Bourns | SRN5040-6R8M | 6.8uH | SRN5040 | INDUCTOR | SRN5040-6R8MCT-ND | Inductor semi-shielded 6.8 uH 20% Wire-Wound 2.3A
9 | POWER_SW. | 1 | JST | B2B-PH-SM4-TB | Connector | B2B-PH-SM4-TB | CONNECTOR JST 2-PH | 455-2872-1-ND | Can substitute B2B-PH-SM4-TBT (pick-and-place compatible version)
10 | PX1. | 1 | WorldSemi | WS2813B |  | WS2813 | RGB LED |  | Alternative part code WS2813B-RGB | Must be WS2813 not WS2812!
10 | PX2. | 1 | WorldSemi |  |  | WS2813 | RGB LED |  | Alternative part code WS2813B-RGB | Must be WS2813 not WS2812!
10 | PX3. | 1 | WorldSemi |  |  | WS2813 | RGB LED |  | Alternative part code WS2813B-RGB | Must be WS2813 not WS2812!
10 | PX4. | 1 | WorldSemi |  |  | WS2813 | RGB LED |  | Alternative part code WS2813B-RGB | Must be WS2813 not WS2812!
10 | PX5. | 1 | WorldSemi |  |  | WS2813 | RGB LED |  | Alternative part code WS2813B-RGB | Must be WS2813 not WS2812!
10 | PX6. | 1 | WorldSemi |  |  | WS2813 | RGB LED |  | Alternative part code WS2813B-RGB | Must be WS2813 not WS2812!
10 | PX7. | 1 | WorldSemi |  |  | WS2813 | RGB LED |  | Alternative part code WS2813B-RGB | Must be WS2813 not WS2812!
10 | PX8. | 1 | WorldSemi |  |  | WS2813 | RGB LED |  | Alternative part code WS2813B-RGB | Must be WS2813 not WS2812!
10 | PX9. | 1 | WorldSemi |  |  | WS2813 | RGB LED |  | Alternative part code WS2813B-RGB | Must be WS2813 not WS2812!
10 | PX10. | 1 | WorldSemi |  |  | WS2813 | RGB LED |  | Alternative part code WS2813B-RGB | Must be WS2813 not WS2812!
10 | PX11. | 1 | WorldSemi |  |  | WS2813 | RGB LED |  | Alternative part code WS2813B-RGB | Must be WS2813 not WS2812!
10 | PX12. | 1 | WorldSemi |  |  | WS2813 | RGB LED |  | Alternative part code WS2813B-RGB | Must be WS2813 not WS2812!
10 | PX13. | 1 | WorldSemi |  |  | WS2813 | RGB LED |  | Alternative part code WS2813B-RGB | Must be WS2813 not WS2812!
10 | PX14. | 1 | WorldSemi |  |  | WS2813 | RGB LED |  | Alternative part code WS2813B-RGB | Must be WS2813 not WS2812!
10 | PX15. | 1 | WorldSemi |  |  | WS2813 | RGB LED |  | Alternative part code WS2813B-RGB | Must be WS2813 not WS2812!
10 | PX16. | 1 | WorldSemi |  |  | WS2813 | RGB LED |  | Alternative part code WS2813B-RGB | Must be WS2813 not WS2812!
10 | PX17. | 1 | WorldSemi |  |  | WS2813 | RGB LED |  | Alternative part code WS2813B-RGB | Must be WS2813 not WS2812!
10 | PX18. | 1 | WorldSemi |  |  | WS2813 | RGB LED |  | Alternative part code WS2813B-RGB | Must be WS2813 not WS2812!
10 | PX19. | 1 | WorldSemi |  |  | WS2813 | RGB LED |  | Alternative part code WS2813B-RGB | Must be WS2813 not WS2812!
10 | PX20. | 1 | WorldSemi |  |  | WS2813 | RGB LED |  | Alternative part code WS2813B-RGB | Must be WS2813 not WS2812!
10 | PX21. | 1 | WorldSemi |  |  | WS2813 | RGB LED |  | Alternative part code WS2813B-RGB | Must be WS2813 not WS2812!
10 | PX22. | 1 | WorldSemi |  |  | WS2813 | RGB LED |  | Alternative part code WS2813B-RGB | Must be WS2813 not WS2812!
10 | PX23. | 1 | WorldSemi |  |  | WS2813 | RGB LED |  | Alternative part code WS2813B-RGB | Must be WS2813 not WS2812!
10 | PX24. | 1 | WorldSemi |  |  | WS2813 | RGB LED |  | Alternative part code WS2813B-RGB | Must be WS2813 not WS2812!
10 | PX25. | 1 | WorldSemi |  |  | WS2813 | RGB LED |  | Alternative part code WS2813B-RGB | Must be WS2813 not WS2812!
10 | PX26. | 1 | WorldSemi |  |  | WS2813 | RGB LED |  | Alternative part code WS2813B-RGB | Must be WS2813 not WS2812!
10 | PX27. | 1 | WorldSemi |  |  | WS2813 | RGB LED |  | Alternative part code WS2813B-RGB | Must be WS2813 not WS2812!
10 | PX28. | 1 | WorldSemi |  |  | WS2813 | RGB LED |  | Alternative part code WS2813B-RGB | Must be WS2813 not WS2812!
10 | PX29. | 1 | WorldSemi |  |  | WS2813 | RGB LED |  | Alternative part code WS2813B-RGB | Must be WS2813 not WS2812!
10 | PX30. | 1 | WorldSemi |  |  | WS2813 | RGB LED |  | Alternative part code WS2813B-RGB | Must be WS2813 not WS2812!
10 | PX31. | 1 | WorldSemi |  |  | WS2813 | RGB LED |  | Alternative part code WS2813B-RGB | Must be WS2813 not WS2812!
10 | PX32. | 1 | WorldSemi |  |  | WS2813 | RGB LED |  | Alternative part code WS2813B-RGB | Must be WS2813 not WS2812!
10 | PX33. | 1 | WorldSemi |  |  | WS2813 | RGB LED |  | Alternative part code WS2813B-RGB | Must be WS2813 not WS2812!
10 | PX34. | 1 | WorldSemi |  |  | WS2813 | RGB LED |  | Alternative part code WS2813B-RGB | Must be WS2813 not WS2812!
10 | PX35. | 1 | WorldSemi |  |  | WS2813 | RGB LED |  | Alternative part code WS2813B-RGB | Must be WS2813 not WS2812!
10 | PX36. | 1 | WorldSemi |  |  | WS2813 | RGB LED |  | Alternative part code WS2813B-RGB | Must be WS2813 not WS2812!
11 | Q1 | 1 | ON Semiconductor | MMUN2133LT1G | PNP | sot23-3-123 | TRANSISTOR
12 | R1 | 1 |  |  | 5.1k | 1206 | RESISTOR |  | Please supply quality generic 1%
12 | R2 | 1 |  |  | 5.1k | 1206 | RESISTOR |  | Please supply quality generic 1%
12 | R3 | 1 |  |  | 5.1k | 1206 | RESISTOR |  | Please supply quality generic 1%
12 | R17 | 1 |  |  | 5.1k | 1206 | RESISTOR |  | Please supply quality generic 1%
13 | R10 | 1 |  |  | 1k | 1206 | RESISTOR |  | Please supply quality generic 1%
13 | R11 | 1 |  |  | 1k | 1206 | RESISTOR |  | Please supply quality generic 1%
13 | R8 | 1 |  |  | 1k | 1206 | RESISTOR |  | Please supply quality generic 1%
13 | R4 | 1 |  |  | 1k | 1206 | RESISTOR |  | Please supply quality generic 1%
13 | R18 | 1 |  |  | 1k | 1206 | RESISTOR |  | Please supply quality generic 1%
13 | R22 | 1 |  |  | 1k | 1206 | RESISTOR |  | Please supply quality generic 1%
14 | R5 | 1 |  |  | 100k | 1206 | RESISTOR |  | Please supply quality generic 1%
14 | R15 | 1 |  |  | 100k | 1206 | RESISTOR |  | Please supply quality generic 1%
14 | R7 | 1 |  |  | 100k | 1206 | RESISTOR |  | Please supply quality generic 1%
14 | R19 | 1 |  |  | 100k | 1206 | RESISTOR |  | Please supply quality generic 1%
15 | R9 | 1 |  |  | 2.21k | 1206 | RESISTOR |  | Please supply quality generic 1%
16 | R6 | 1 |  |  | 270k | 1206 | RESISTOR |  | Please supply quality generic 1%
17 | R21 | 1 |  |  | 330k | 0805 | RESISTOR |  | Please supply quality generic 1%
18 | R14 | 1 |  |  | 1.80M | 0805 | RESISTOR |  | Please supply quality generic 1%
18 | R20 | 1 |  |  | 1.80M | 0805 | RESISTOR |  | Please supply quality generic 1%
19 | R16 | 1 |  |  | 200k | 0805 | RESISTOR |  | Please supply quality generic 1%
20 | THERM | 1 | AVX | NB20K00103JBA | B=3630±3%, a=-4, 10k, NCP | 1206 | THERMISTOR | NB20K00103JBA-ND
21 | U2 | 1 | TE Connectivity | EDS06SGNNTR04Q | 6-way DIP switch | SBS-61006-dip-switch | SWITCH |  | If necessary can substitute Omron Electronics A6SN-6104
22 | U3. | 1 | Maxim | MAX3371EXT+T | IC, level converter | SC70-6 | IC LEVEL CONVERTER | MAX3371EXT+TCT-ND
23 | U4. | 1 | Microchip | MCP73871-2CCI/ML | IC, LiPo battery manager | QFN20 | IC LIPO CHARGER | MCP73871-2CCI/ML-ND
24 | U5. | 1 | TI | TPS61090RSAR | IC, boost converter | QFN16-TPS6109 | IC BOOST CONVERTER | 296-15259-1-ND
25 | U6. | 1 | ROHM | BD33IA5WEFJ-E2 | IC, LDO regulator 3.3V | HTSOP-J8 | IC REGULATOR | BD33IA5WEFJ-E2CT-ND
26 | U7. | 1 | ST Microelectronics | LPS35HWTR | IC, pressure sensor | CCLGA-10L | IC PRESSURE SENSOR | 497-16706-1-ND
27 | U8. | 1 | ST Microelectronics | LSM6DSOTR | IC, accelerometer | LGA-14L | IC ACCELEROMETER | 497-18181-1-ND
28 | USB. | 1 | Valcon | CSP-USC16-TR | Valcon CSP-USC16-TR | usb-c-female-ra-valcon-csp-usc16-tr | CONNECTOR USB-C |  | Kitted/consigned (customer will supply)
29 | Z1 | 1 | ON Semiconductor | MM3Z3V9ST1G | 4.2V zener diode | SOD-323 | ZENER | MM3Z3V9ST1GOSCT-ND
30 | Z2 | 1 | Littelfuse | SMBJ5.0A | TVS protection diode | DO214AA | DIODE TVS | SMBJ5.0ALFCT-ND

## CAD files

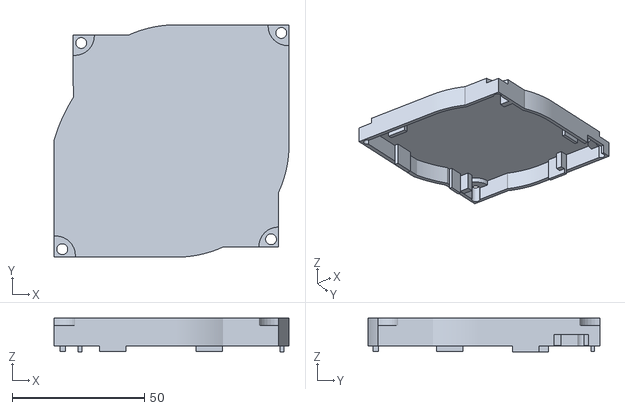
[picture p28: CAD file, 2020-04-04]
case/010-lid.stl
89.0 x 88.0 x 12.7

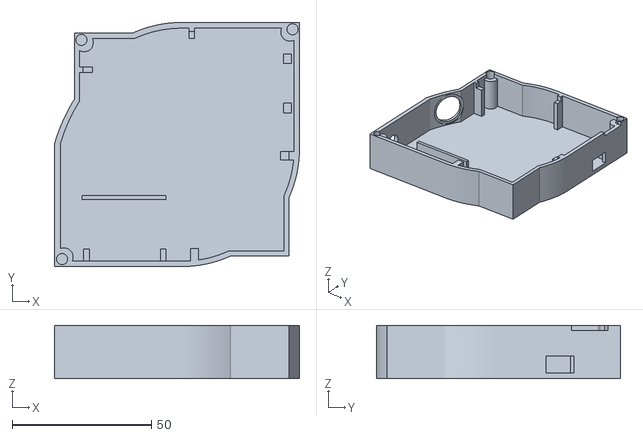
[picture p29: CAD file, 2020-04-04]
case/009-base.stl
88.0 x 87.7 x 19.1

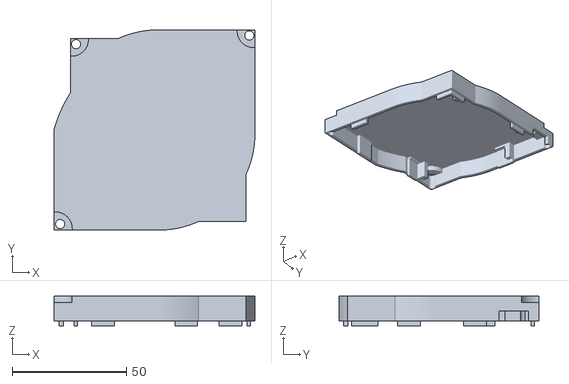
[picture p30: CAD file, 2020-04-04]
case/009-lid.stl
88.0 x 87.7 x 12.9

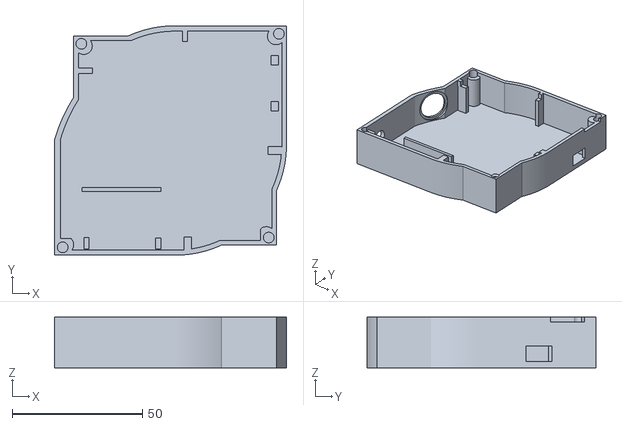
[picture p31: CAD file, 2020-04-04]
case/010-base.stl
89.0 x 88.0 x 19.4

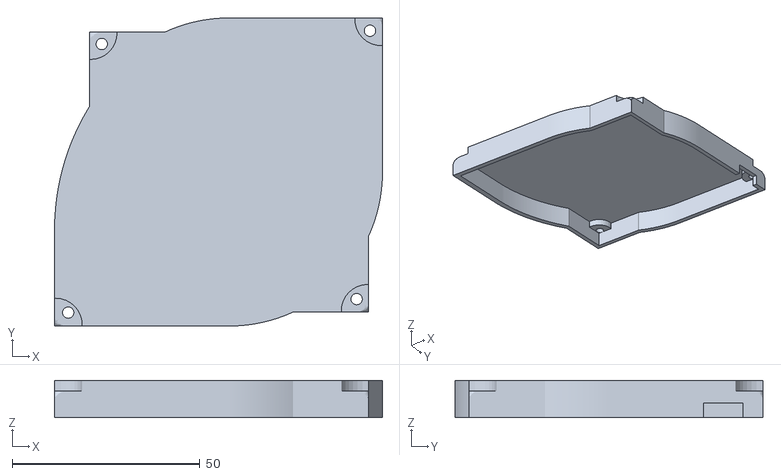
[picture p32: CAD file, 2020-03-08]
case/007-caselid-final-lid.stl
87.3 x 82.0 x 9.90

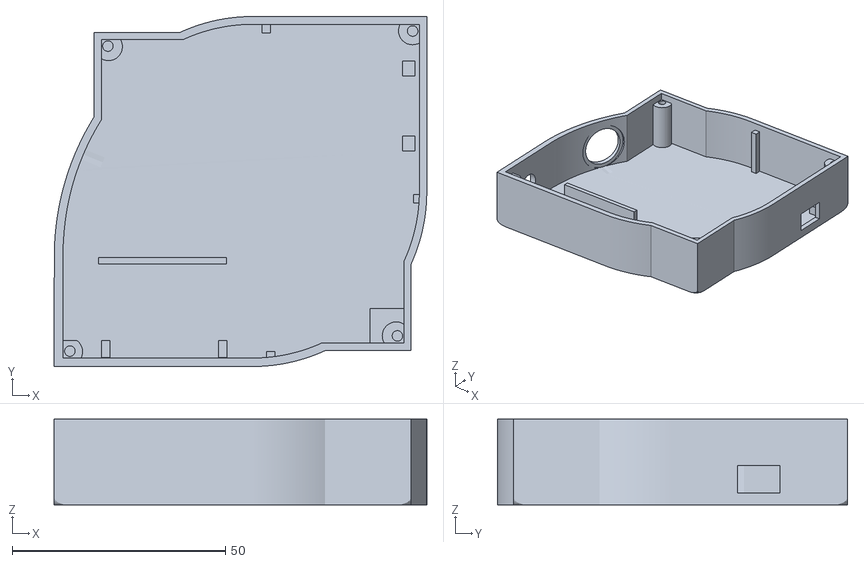
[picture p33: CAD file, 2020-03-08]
case/007-caselid-final-base.stl
87.3 x 82.0 x 20.1

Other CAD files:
case/007-caselid-final.blend

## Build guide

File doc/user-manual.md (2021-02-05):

# paradar user manual

Last update: February 2021. See https://github.com/blinken/paradar/tree/master/doc/user-manual.md for the
latest version.

| Serial number | |
| --- | ---|

BLINKENLIGHT Ltd, Lytchett House, 13 Freeland Park, Wareham Road, Poole, BH16 6FA<br/>
info@paradar.co.uk

## Overview

Thanks for purchasing paradar! paradar is open-source hardware and software,
and your purchase funds further development.

paradar is a tiny, handheld, self-contained ADS-B indicator for paramotor,
paraglider, drone and general aviation pilots. It helps increase your
situational awareness by indicating aircraft in the sky around you, if they are
transmitting ADS-B.

**paradar does not replace your responsibility to look for, see and avoid other
aircraft. This device will not save your life. It is intended only to provide
additional situational awareness of some traffic around you when flying VFR. It
is not designed for and must not be used for IFR flight, and you must not rely
on it when flying in any conditions.**

paradar receives ADS-B radio transmissions from other aircraft, which contain
location information. It also contains a GPS receiver and a compass, and
calculates the bearing from your position to the other aircraft, which is then
indicated on a ring of bright LEDs. Because paradar relies on other aircraft
transmitting their position, it will pick up many aircraft but not all: some
older airframes are still not equipped with modern ADS-B transponders. This
proportion is decreasing, however, as ADS-B is mandated by regulators around
the world.

paradar is open source hardware and software. If you have an idea for a
feature or improvement, or encounter a bug, please report it at https://github.com/blinken/paradar/issues
(see the bug reports section below for more information).

For general queries, including bulk order discounts, you're welcome to contact
me at info@paradar.co.uk.

Happy flying!

*-Patrick*

## Safety information
To prevent possible electrical shock, fire, personal injury, or damage to the
product, read this safety information carefully before attempting to install or
use the product. In addition, follow all generally accepted safety practices
and procedures for working with or near electricity.

### Symbols and terminology

The following safety descriptions and symbols are found thoughout this guide:

* A **WARNING** identifies conditions or practices that could result in injury
  or death.
* A **CAUTION** identifies conditions or practices that could result in damage
  to the product or equipment to which it is connected.

| Symbol | Description |
| :----: | --- |
| Electric shock | Possibility of electric shock. Risk of injury or death. |
| Caution | Caution. Risk of damage to the product or attached equipment. |
| WEEE | Do not dispose of this product as unsorted muncipal waste. |

### General safety information

> Electric shock
> 
> **WARNING** To prevent injury or death, use
> the product only as instructed and use only the accessories that have been
> supplied or recommended. Protection provided by the product may be impaired if
> used in a manner not specified by the manufacturer.
> 
> **WARNING** To prevent injury or death, do not use in wet or damp conditions,
> or near explosive gas or vapour.
> 
> **WARNING** paradar contains a rechargeable lithium-polymer battery. Do not use
> the device outside of the recommended operating conditions. Do not burn or
> crush, or otherwise damage or modify the outer case. Do not attempt to directly
> charge the battery; only use the USB-C port integrated into paradar.

### Operating environment

| | Storage | Operating (including charging) |
| - | --- | --- |
| Temperature | 0°C to +55°C | 5°C to +50°C |
| Humidity | 5% to 95% RH (non-condensing) | 5% to 80% RH (non-condensing) |
| Magnetic field | - | -400 to 400 µT |

Keep paradar away from strong magnets and magnetic fields while in use. Keep
paradar well away from fuels (including fuel vapour), oils and solvents.

> Caution
> 
> **CAUTION** To prevent damage, always use and store paradar in appropriate
> environments.

### Care and cleaning

paradar contains user-servicable configuration switches on the top circuit
board, which can be accessed by removing the top cover using the four top
screws. Do not attempt to disassemble the device further; repair, servicing and
calibration require specialised test equipment.

To clean, ensure the top cover is firmly attached, and wipe only the outside of
the case with a damp, clean, soft cloth using a solution of mild soap or
detergent and water. Do not attempt to clean the circuit board or other
internal components.

Keep paradar well away from fuels (including fuel vapour), oils and solvents.

> Electric shock
> 
> **WARNING** To prevent injury or death, do not touch any electronic or internal
> component except the user configuration switches as instructed in this manual.
> 
> **WARNING** To prevent injury or death, do not use the product if it appears to
> be damaged in any way, and stop using immediately if you are concerned by any
> abnormal operations.
> 
> **WARNING** When cleaning paradar, use a soft cloth and a solution of mild soap
> or detergent in water. To prevent electric shock, do not allow water to enter
> the casing as this will compromise the electronics or insulation inside.

## Getting started

paradar is pretty easy to use!

1. Ensure the antenna is attached. The longer antenna is more sensitive, but also more bulky.
1. Turn paradar on using the power switch on the side. A small green LED in the
   center of the unit will light up.
1. Wait 30-40 seconds for the software to initialise.
1. The main display will start and show a spinning white dot. This indicates
   paradar is searching for a GPS signal. Make sure the top case is pointing
   upwards and it has an unobstructed view of the sky, and keep it in one place
   until it locates the GPS signal (30-120 seconds).
1. When paradar locks on to the GPS signal, the display will briefly change to
   a solid white ring.

You're up and running! paradar can show several things on the display via
coloured lights, all of which will move together as the device is rotated:

* White light: indicates compass north. Can be enabled/disabled (see below).
* Green light: guide-me-home indicator, showing that home is greater than 15
  meters away. Indicates the direction to the location the device was turned
  on. Can be enabled/disabled (see below).
* Teal light: guide-me-home indicator, showing that home is less than 15 meters
  away. When home is <15m away, the bearing is always shown as due south. Can
  be enabled/disabled (see below).
* Blue light: indicates an aircraft - far away (between 15km and 30km distant)
* Purple/red light: indicates an aircraft - nearby (less than 15km distant). The
  colour fades slowly from blue to red as the aircraft comes closer - a bright
  red light indicates that the aircraft is very close.
* Light orange light: altitude indicator in flight mode. See more on this below.

Note that aircraft distance indication (the colour of an aircraft indicator
light, from blue -> red) only considers the horizontal distance. That is, an
aircraft directly overhead but 30,000ft higher than paradar will be displayed
bright red.

The distance from which you can receive other aircraft depends on the antenna
and clearance from nearby obstacles (buildings, trees, terrain). Outdoors,
clear of obstructions, with a good line of sight in all directions, the
included 2dBi (10cm) antenna will receive large aircraft 20-30km away. A 5dBi
antenna (20cm) or a larger magnetic-mounted whip placed in a high location (eg,
a vehicle roof) will receive more distant aircraft.

paradar uses a female SMA antenna connector (the antenna must have a male SMA
connector). If you break the antenna, contact info@paradar.co.uk and we'll send
you a new one, if you cover postage.

> Caution
> 
> **CAUTION** If attaching an antenna not supplied by the manufacturer, ensure it
> is tuned to 1090MHz (and optionally 978MHz in the USA). It must have 50 ohm impedance and a
> male SMA connector. Turn off paradar and disconnect the antenna if you receive
> reports of interference with other equipment.

To avoid display clutter, paradar will not display aircraft further than 30km
away, even if it can hear them. If connected to SkyDemon or another
GDL90-compatible app (see below), it will send all aircraft it can hear to the
app.

## What is ADS-B?

ADS-B (Automatic Dependent Surveillance Broadcast) is a system where aircraft
transmit their position, altitude, speed and heading (and plenty of other
information) every few seconds on a specific radio frequency. Transmit power
varies from 20W up to 500W, which means the transmissions can be heard by a
radio receiver a _very_ long way away.

The radio frequency used is 1090Mhz (most countries) or 978MHz ("UAT", largely
US-only).

There are a number of alternative standards, such as FLARM (which is popular
amongst ultralight aircraft in Europe) and the Open Glider Network (largely
UK/Europe). ADS-B however is rapidly becoming the global standard for fixed-wing
aircraft - which are the kind of aircraft paramotor and drone pilots want to
avoid at all costs!

References and further information:

* https://en.wikipedia.org/wiki/Automatic_dependent_surveillance_%E2%80%93_broadcast
* https://www.caa.co.uk/General-aviation/Aircraft-ownership-and-maintenance/Electronic-Conspicuity-devices/
* https://www.faa.gov/nextgen/programs/adsb/

### Can other aircraft see transmissions from paradar?

paradar is a receive-only device; it does not transmit. It's intended to give
you an indication of some of the traffic around you - to help you decide
whether to take off, and to help you identify other aircraft when in the air.

However, if you're flying near a location where fixed-wing aircraft operate,
it's a _really good idea_ to carry an ADS-B transmitter so you are visible to
other pilots and any air traffic control. A great option is the [uAvionix
SkyEcho 2](https://uavionix.com/products/skyecho/). This has been tested and
will work well alongside paradar.

Drone pilots should consider equipping with
a [uAvionix ping1090](https://uavionix.com/products/ping1090/), if possible.

## Battery life, care and feeding

Paradar has a 2,000mAh internal battery. Battery life is approximately 2.5
hours (with display set to medium brightness and wifi turned off). The low
battery indicator (a small, red light in the center of the device) will come on
when you have approximately 30 minutes remaining.

Charge the battery by carefully connecting a USB-C cable to the port on the
side.

* An orange LED in the center of the device indicates the battery is
  charging
* A green LED indicates charging is complete.
* A red LED indicates low battery.
* If two lights (orange, green) are illuminated when the power is switched off,
  or you see three lights (green/orange/green) with the power switched on, the battery is
  too hot to charge. Disconnect the charger, turn paradar off and allow it
  to cool down.

paradar can be switched on or off while the battery is charging, though it will
charge slightly faster when switched off.

You can also run paradar continuously connected to an external USB battery pack
or 5V power source.  It can be run continuously off a USB-C power supply for
use on the ground or as part of a flight deck. **A good setup is a 10,000mAh
USB battery pack stored in a pocket of your flight deck, and permanently
attached to paradar via a short cable.  This can extend the run time by 5-10x,
depending on battery pack size.** Contact us if you need recommendations.

The case is made of PET plastic, which is resistant to most solvents and
somewhat resistant to fuels. paradar is not waterproof. Wipe the case clean
using a damp rag.

> Caution
> 
> **CAUTION** For reliable operation and to prevent damage, follow the
> requirements below.
> 
> * paradar consumes 5W (1A) in operation, and up to 12W (2.5A) when charging. For
>   best results **use a good quality USB power supply rated to at least 3A, and a
>   good quality USB-C cable.** Weaker power supplies (eg, a laptop USB port) will
>   work, though the battery may still discharge if paradar is running and
>   charging at the same time (you'll still get a longer run time than battery alone).
> * Keep the device as level as possible to ensure the compass reading is accurate.
> * The compass used by paradar has a very high dynamic range, and will work well
>   in difficult magnetic environments. However, it is still susceptible to
>   interference. Keep paradar a few centimeters away from metal of any sort, and
>   well away from strong magnetic fields such as electric motors.
> * Don't leave paradar in hot environments or very strong sunlight (where it can
>   heat up). It will slow down processing and disable battery charging if the
>   external temperature exceeds approximately 50 degrees Celcius. Prolonged
>   exposure to higher temperatures (eg, the dashboard of a car on a hot day) may
>   damage the battery.

## Features and configuration

paradar has six configurable feature switches just under the main lid.

To access them, remove the four screws on the top surface using a 2.5mm hex bit
or allen key, and carefully remove the lid. Be cautious not to yank on the main
circuit board just underneath as the lid comes off.

Orient the device so the USB-C connector is at the top-right. The six
configuration switches are very small and located on the center-right of the
main board. Each switch has a number printed below.

To turn a switch on, move it to the upper position (towards the ON marking). To
turn it off, move it down.

> Electric shock
> 
> **WARNING** To prevent injury or death, do not touch (with fingers or tools)
> any electronic component except those described below. Ensure the power switch
> is turned off and the device is unplugged. Note that this reduces risk but does
> not de-energise the device, as it contains a battery.
> 
> **WARNING** Some parts of the device get very hot in normal operation. Be cautious.

> Caution
> 
> **CAUTION** Ensure you work in a clean environment, to avoid damage to
> paradar's SD card or internal electronics.
> 
> **CAUTION** The main LEDs may be damaged if you touch them with your finger or
> a sharp tool.

### Switch function overview

| Switch # | Function | On | Off |
|---|---|----|-----|
| 1 | LED brightness control | High brightness | Medium brightness |
| 2 | Wifi control | Wifi hotspot enabled | Wifi hotspot disabled (saves power) |
| 3 | Guide-me-home (green/teal indicator) | Feature enabled | Feature disabled |
| 4 | Compass north (white indicator) | North shown | North not shown |
| 5 | Flight mode | Aircraft are only shown if within 3000ft of the current altitude, or less than 15km away | All aircraft closer than 30km are shown |
| 6 | Dual-mode 978Mhz operation | Device switches between 1090Mhz and 978Mhz reception periodically (for use in the USA) | Device listens continuously on 1090MHz (all other regions) |

It's fine to run paradar with the cover off for testing. You can change the
switch positions with the unit running, and they will have immediate effect. **Be
careful not to touch any electronic component, and be wary as some parts of the
board get very hot in normal operation.**

Don't run paradar with the cover off outdoors.

### LED brightness

The main display uses extremely bright LEDs, designed to be easily readable in
full sun. For use in shaded environments, or indoors, set the display to medium
brightness by setting switch #1 to OFF. This will save significant battery
power, particularly when there are a lot of aircraft nearby.

### Wifi and GDL90 (SkyDemon) support

paradar has an optional built-in wifi hotspot that allows you to provide
high-quality GPS and traffic information to a Garmin GDL90-compatible app on
your portable device or laptop. This lets you:

 * Record your flight using a better quality GPS than that available in your phone
 * See air traffic nearby displayed on a map
 * See air traffic further than 30km away (paradar will not display very
   distant aircraft, to avoid cluttering the display).

This feature has been tested with SkyDemon, but many apps support the Garmin
GDL90 protocol - ForeFlight, FlyQ, Naviator, WingX Pro, Droid EFB and more.

To enable the wifi hotspot, set switch #2 to ON. The wifi consumes the device's battery
faster. Turn it off when you're not planning on using it.

    SSID: paradar
    Password: radarapp

1. Connect your phone, tablet or laptop to the "paradar" hotspot using the
password above ("pparadar" backwards).
    * Internet access will not be available.
1. Open SkyDemon, and tap the Settings icon (the cog at the top-left of the display)
1. Select third-party devices, and tick the box next to "GDL90 compatible device".
1. Return to the main screen.
1. When you are ready, tap Go Flying at the top right of the display.
1. Select "Use GDL90 Compatible Device" when prompted.
1. SkyDemon will briefly show "Waiting for Device", which should disappear once
   it begins receiving data from paradar.

Altitude will be displayed under the "ALT" icon, and the current location will
be updated from paradar's GPS. Other aircraft will be visible as small, moving
icons against the map.

**paradar's wifi hotspot is very simple. Two paradars near each other will
interfere and good results are not guaranteed.**

### Guide-me-home

This feature allows you to record your takeoff point, and paradar will calculate
the bearing back home from your current location and display it with a green
light.

The saved home location is only held while paradar is running - it is deleted
when paradar is turned off (or the configuration switch is turned off). The
home location is recorded when paradar starts, or when the configuration switch
is turned on (if it is turned on when paradar is running).

When you are within 15 meters of the recorded home location (eg, before
takeoff) the bearing will always be shown as due south (180 degrees). This is
to avoid the display changing continuously due to GPS position error.

paradar will indicate you are close to home with a teal (blue-green) light when
you are within 15 meters.

When you are more than 15 meters from the recorded home location, paradar will
indicate the direction to home from the current position with a bright green
light.

To enable this feature, set switch #3 to ON.

### Compass north indicator

paradar can indicate compass north as a bright white LED. This is useful to
give you confidence that the compass is working without interference.

To indicate north, set switch #4 to ON.

### Flight mode

Flight mode is intended for use when flying, and has two features.

1. When activated, paradar will only show aircraft in a bubble of +/- 3000ft
   from the current altitude, and less than 15km distant. All other aircraft
   are hidden (but still sent via the WiFi link, if enabled). This is useful to
   avoid displaying large jets cruising at 35,000ft when you are flying low.

1. When paradar is turned on, the initial altitude is stored (this is reset
   when you turn it off again). Relative to the turn-on altitude, paradar will
   display an altimeter scale on the display between 20ft and 1000ft above the
   turn-on altitude. This is shown in light orange, as a "background" to other
   indicators (ie. North, Guide-me-home, and traffic all show on top of the
   altimeter).

   Note that long periods of flying at just below 1000ft will rapidly drain the
   battery, as all LEDs will be lit.

**The altimeter is based on barometric pressure using the IACO standard pressure
altitude model (on v1.5 hardware, white PCB) or GPS altitude (v1.4 hardware,
green PCB). It will be affected by changes in barometric pressure due to
weather conditions, or by interference with the GPS signal.**

**Do not rely on the altimeter function. It indicates pressure altitude, NOT
height-above-ground.**

To activate flight mode, set switch #5 to ON.

### Dual-band 978MHz+1090MHz operation

If you're operating in a region where 978Mhz (or "UAT") transmissions are used,
it is necessary to receive on both 978MHz and 1090Mhz to see all aircraft. This
usually means you're flying in the USA.

paradar can receive on 978Mhz in addition to 1090Mhz, but it only has one radio
receiver. It achieves dual-band operation by switching between 978MHz and
1090Mhz reception approximately every 10-20 seconds. Aircraft retransmit their
location very frequently, so this provides good coverage of both bands at the
expense of slightly delayed updates.

To enable dual-mode operation, set switch #6 to ON. This should be turned off
outside of the US.

Caveat - the antenna supplied with paradar is tuned to 1090Mhz. It will still
receive strong signals on 978Mhz, but reception will be weaker. However, even
in the US 1090MHz is the predominant frequency in use for air-to-air position
transmission.

## Software updates

> Electric shock
> 
> **WARNING** To prevent injury or death, do not touch (with fingers or tools)
> any electronic component except those described below. Ensure the power switch
> is turned off and the device is unplugged. Note that this reduces risk but does
> not de-energise the device, as it contains a battery.
> 
> **WARNING** Some parts of the device get very hot in normal operation. Be cautious.

> Caution
> 
> **CAUTION** Ensure you work in a clean environment, to avoid damage to
> paradar's SD card or internal electronics.

To perform a software update, you'll need to remove the microSD card that holds
paradar's software. This is a bit of a delicate process - set yourself up on a
table with plenty of light.

1. Remove the four screws on the top surface using a 2.5mm hex bit or allen
   key, and carefully remove the lid. Be cautious not to yank on the main
   circuit board just under the lid.
1. Carefully loosen the nut that holds on the antenna connector. Be careful not
   to damage the antenna connector thread.
1. The SD card lives under the main circuit board on the left side - directly
   across from the USB-C connector.
1. Gripping the GPS antenna, cautiously lift the main circuit board by no more
   than 2-3cm (watch out for the tiny wires underneath).
1. Carefully remove the microSD card from the holder.

When a software update is released, it will come with instructions on what to
do next.

To re-install:

1. Insert the microSD card, contacts facing down, back where it came from -
   make sure it's fully seated in the silver card holder. It's normal that it
   sticks out slightly, and it's a friction fit only (there's no "click", it
   just slides in).
1. Make sure the main circuit board is gently seated in the center of the
   bottom case. The top of the circuit board should be level with the top of
   the case walls, and there should be an even gap around all sides.

   Sometimes, a connector under the top of the display blocks re-installation.
   Gently poke it with a small allen key or similar, so the main circuit board
   sits flat.
1. Re-attach the lid, being cautious that the tabs on the bottom of the lid fit
   in the gap between the main PCB and the side of the bottom case.
1. Reinstall all four lid screws and gently tighten. They do not need to be
   very tight. Retighten the antenna connector nut.

## Bug reports, feature requests and support

paradar is open hardware and open source software. This means that you can view
all the source code and hardware design files online, at https://github.com/blinken/paradar.
You can also contribute to development by raising a pull request.

Feature requests and bug reports are welcome. Please open an issue at
https://github.com/blinken/paradar/issues. For bug reports, please include as
much information as you possibly can about what you were doing.

For general queries (including bulk order discounts), you can contact Patrick
directly at patrick@paradar.co.uk.

## Disclaimer and license

 

Electric shock

**paradar does not replace your responsibility to look for, see and avoid
other aircraft.** This device will not save your life, and you must ensure
you have appropriate flight-rated equipment to operate your aircraft.
paradar is intended only to provide additional situational awareness of
some traffic around you when flying VFR. It is not designed for and must
not be used for IFR flight, and you must not rely on it when flying in any
conditions.

paradar takes the place of a phone or tablet and app when flying, and aims
to provide useful information to a pilot. **The information provided by
paradar is not guaranteed to be correct and may fail without warning.
paradar is not suitable and must not be used to operate or control an
aircraft, and must not be relied upon for safety or the safe operation of
an aircraft.  It is not suitable and must not be used for the navigation of
an aircraft.**

**The pilot is responsible for the safe conduct of any flight, for ensuring
they have appropriate flight rated equipment alongside paradar and for
obeying all applicable laws.**

Copyright (C) 2021 Patrick Coleman

paradar is free software; you can redistribute it and/or modify
it under the terms of the GNU General Public License as published by
the Free Software Foundation; either version 3 of the License, or
(at your option) any later version.

paradar is distributed in the hope that it will be useful,
but WITHOUT ANY WARRANTY; without even the implied warranty of
MERCHANTABILITY or FITNESS FOR A PARTICULAR PURPOSE.  See the
GNU General Public License for more details.

You should have received a copy of the GNU General Public License along
with this program; if not, write to the Free Software Foundation, Inc.,
51 Franklin Street, Fifth Floor, Boston, MA 02110-1301 USA.

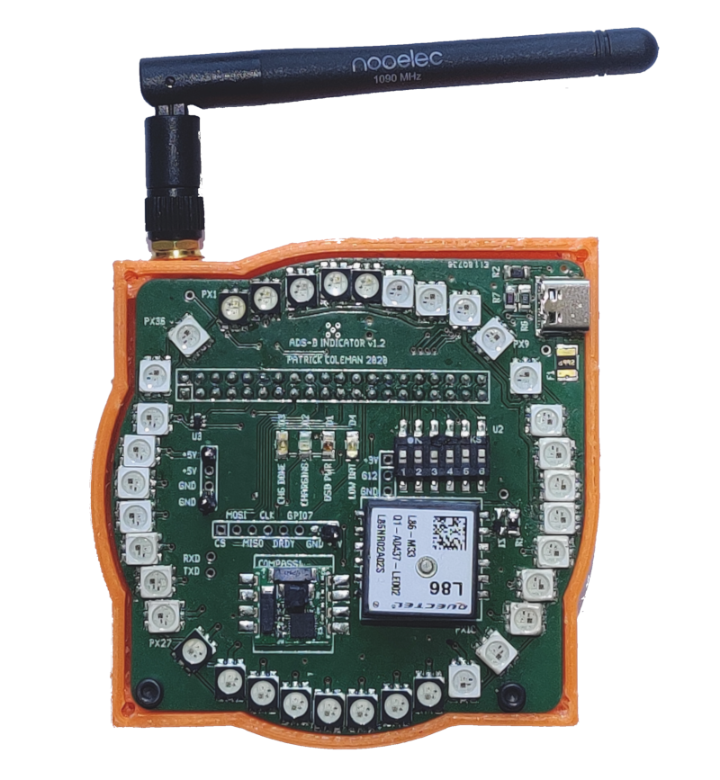
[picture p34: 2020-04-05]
doc/images/paradar-v1.2-assembled-withcase-800.png

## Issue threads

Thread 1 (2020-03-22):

gdl90 heading should use compass azimuth

blinken, 2020-03-22:
Currently we use the GPS heading, but compass azimuth would be much better. Requires some documentation and maybe stickers on the case indicating the correct orientation for the chassis for this to work.

blinken, 2020-07-20:
Maybe this depends on a gyro-corrected compass, as described in #4

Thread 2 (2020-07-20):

Limit aircraft displayed to a cylinder around the aircraft

blinken, 2020-07-20:
### Background
Currently, "flight mode" limits aircraft shown to those less than 10,000ft altitude, to filter out jets. On busy days, this often isn't sufficient to filter out targets to ignore, because receive distance is many tens of kilometers.

### Proposal
It would be better to show aircraft only within a cylinder around the current altitude and location. Other EC systems use 3,500ft altitude and 10nm distance, but figures around this number seem reasonable.

blinken, 2021-03-16:
This is done in v1.5-rc2

Closed 2021-03-16.

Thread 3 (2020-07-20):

Tilt-compensate compass with accelerometer

blinken, 2020-07-20:
### Background
The compass is unstable when tilted away from horizontal, because we're only considering the X/Y magnetic field strength readings.

### Proposal

Use the tilt information in the accelerometer to tilt-compensate (stabilise) the compass, so it's more intuitive for the user. See equations in Frick (https://ir.uiowa.edu/cgi/viewcontent.cgi?article=6952&context=etd) p44

blinken, 2020-07-21:
This is done in 7fa532b0e3505a73848b4673a12fc9747ed15e2d, but I'll wait until that branch is merged before closing this.

Closed 2020-07-27.

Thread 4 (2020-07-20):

Use gyroscope information to help filter out magnetic interference

blinken, 2020-07-20:
### Background
The compass is prone to magnetic interference, so it doesn't point to true north if it's on a ferromagnetic surface.

### Proposal
Filter out magnetic interference by using the gyroscope to test whether the device is _actually_ being rotated when the compass reports a rotation. A potential algorithm is described in https://ir.uiowa.edu/cgi/viewcontent.cgi?article=6952&context=etd.

Closed 2020-07-27.

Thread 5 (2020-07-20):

Receive P3i

blinken, 2020-07-20:
### Background
P3i (https://pilotaware.com/wp-content/uploads/2017/03/Protocol.pdf) is the open protocol that Pilot Aware uses to transmit beacons from aircraft. Currently we only receive ADS-B, but frequency hopping on the SDR should make this possible.

### Proposal
Write a custom SDR backend that receives multiple open protocols via frequency-hopping (P3i and FANET).

blinken, 2020-07-20:
Consider also whether I can leverage the GPU on the Pi to accelerate the signal processing and decoding (maybe this is too much work).

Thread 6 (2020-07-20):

Indicate pressure altitude during takeoff, landing and low-flying

blinken, 2020-07-20:
### Background

On final approach and shortly after takeoff, it's useful to know the height above the takeoff and landing point.

### Proposal
Display the pressure altitude automatically as a background colour on the display for altitudes less than 1000ft. Enable this only in "flight mode" (which we currently use to limit displayed aircraft).

### Open questions

- What's the impact on battery life?
- Will this be visually distracting? How can it be made easy to read without being visually distracting?
- What colour can I use that's colour-blind appropriate?

blinken, 2021-03-16:
This is done in v1.5-rc2

Closed 2021-03-16.

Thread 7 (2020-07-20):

Indicate the software version number on startup

blinken, 2020-07-20:
### Background
The user doesn't know what version of software they're running, which will be tricky as more devices are out in the field (and more software updates are released).

### Proposal
Provide some easy way to tell what version of software is in use - maybe using "clock hand" indication on the display?

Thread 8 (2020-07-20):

Automatic software updates

blinken, 2020-07-20:
### Background
Manually posting SD cards doesn't scale well. Ideally, devices automatically update themselves when near an internet connection.

### Proposal
Somehow, the user configures their home WiFi details on the device, which then checks for updates. Updates are pretty limited (maybe just a git pull); it must never be possible to brick the device.

### Open questions
 - What's the easiest way for home wifi details to be configured?
 - Does this depend on a web interface?

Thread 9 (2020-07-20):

gdl90 should use pressure altitude

blinken, 2020-07-20:
### Background
GNSS altitude is pretty sub-par, and new boards now have barometric sensors.

### Proposal
Depends on the new sensor backend. Use calibrated pressure altitude in the GDL90 messages rather than GNSS altitude.

Closed 2020-07-28.

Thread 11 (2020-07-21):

Share received signal timing with nearby paragliders to triangulate Mode-S receivers

blinken, 2020-07-21:
### Background
The majority of aircraft currently do not transmit their position information, and rely on ground stations to triangulate them. This is a problem for in-aircraft displays like paradar, because without ground stations feeding us information (or an RF direction finding setup) it's hard to figure out where a mode-S signal comes from.

Pilot Aware/Sky Demon solves this by showing "directionless targets", but I don't like this so much - it seems confusing for the user. Ground stations might let us do MLAT (alternatively, receiving Pilot Aware's data via their module presumably provides this via their ground stations).

### Proposal
Paragliders/paramotors fly in groups with near-ideal separation for triangulation, largely unlike other aircraft. This provides an opportunity to accurately triangulate signals we receive that don't have position information in them - like the bulk of mode-S transponders. Paradar includes a GPS receiver which provides extremely accurate time, and the Raspberry Pi incorporates bluetooth and wifi transmitters. Can these be adapted in software to communicate between adjacent paradars to triangulate mode-s aircraft?

Projects like https://github.com/mutability/mlat-server suggest that this is feasible, and for an aircraft 1km away would require timing of received signals accurate within ~1us. A GPS PPS output is accurate to less than 100ns, though interrupt jitter adds error ~6us - suggesting 6-10km accuracy. This is probably on the lower edge of useful, but feasible for an experiment.

### Open questions
- What's the range on the Pi's WiFi transmitter?
- Could I do this with a software update to the existing SDR platform, or do I need a dedicated 1090Mhz tuner to increase accuracy?
- Could something like linear regression and information sharing between many devices improve overall accuracy?

### Other notes/references
https://www.rtl-sdr.com/thesis-on-locating-transmitters-with-tdoa-and-rtl-sdrs/
file:///home/blinken/Downloads/DPTX_2018_1_11320_0_522240_0_208913.pdf
http://www.rocketmanrc.com/openpps-development.html

Consider extending the hardware platform to add a dedicated 1090Mhz RF frontend, with GPS PPS information muxed in. This would allow very accurate timetstamping of received signals (the PPS is already mixed with the received data) Alternatively, maybe a microcontroller doing the mode-S and a 1090Mhz tuner provides enough accuracy, which can be supported by the Pi or an ESP32.

blinken, 2020-07-21:
Adding a hardware revision label for now, though it may well be possible to do this in software.

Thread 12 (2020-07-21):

Optional buzzer for audio alerts

blinken, 2020-07-21:
### Background
Multiple people have asked to be alerted when new traffic is identified.

### Proposal
Design a buzzer module that connects to the GPIO pin on the top of the board. Consider adding a buzzer to future board revisions. Must be exceptionally loud & support multiple tones.

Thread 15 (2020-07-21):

Integrate the compass module

blinken, 2020-07-21:
### Background
The compass module is expensive, and takes up a lot of space.

### Proposal
Purchase the individual components from PNI and integrate the compass on the board, near the accelerometer and barometric sensors. This should free space for other measurement ICs (eg, counters and timers if required).

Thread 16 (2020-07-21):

Design a dedicated RF frontend

blinken, 2020-07-21:
### Background
The SDR is hot, expensive, and bulky. It would be awesome to not use it, or only use it when absolutely required.

### Proposal 1
Design a simple RF receive frontend for 1090Mhz, and retain the SDR which remains powered down when not required. This would vastly extend battery life, and allow for interesting software improvements in future. Shouldn't need extensive CE certification on the basis that this is only a receiver.

Potentially mux the two receivers into one antenna using something like a Wilkinson divider (? how much space would this require if it's 1/4 wave)

### Proposal 2
Add an RF frontend for 1090Mhz per above, plus something like the HopeRF RFM95 https://www.hoperf.com/modules/lora/RFM95.html, which could receive and transmit a number of different protocols. This would allow integration with P3i or FANET (transmit and receive) though may require a more difficult certification process.

This would allow us to drop the SDR and save a ton of power and space.

Either proposal would assist with #11

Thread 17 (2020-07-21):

Waterproofing

blinken, 2020-07-21:
### Background
The case needs to be even a little bit waterproof.

### Proposal
Find a better USB-C connector and power switch that can work without giant holes in the case. Redesign the case lip to incorporate an oring.

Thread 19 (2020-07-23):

Calculate and display wind direction

blinken, 2020-07-23:
### Background
When I fly, I want to know the wind direction (to help with estimates of fuel consumption, etc). Apps like ppGPS provide this via calculations off the GPS track (ground speed measurements).

### Proposal
Analyse the GPS track and figure out the upwind, crosswind, and downwind legs based on observed ground speed. Indicate this with a particular colour on the display.

### Open questions
 - What colour should this be, to avoid confusion?
 - How should it be enabled and disabled? Does it need to wait on #10?

PhilMad47155, 2021-03-16:
Hy,
Perhaps with few leds in the middle ?

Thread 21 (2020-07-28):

When device is inverted compass flips correctly but aircraft do not

blinken, 2020-07-28:
We correctly flip the compass north when the device is inverted, but don't mirror aircraft correctly to work on an upside-down display. The aircraft are therefore indicated in exactly the opposite direction when the device is inverted.

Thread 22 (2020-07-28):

Indicate when magnetic interference is blocking compass readings

blinken, 2020-07-28:
### Background

The new inertial code is great a masking magnetic interference, but does suffer from slight drift (~0.1 degrees per second, or 6 degrees per minute). This can be interpreted as compass error if the device is left for long periods on a magnetic or metallic surface, such as the bonnet of a car.

### Proposal

Flash the north LED occasionally (two flashes every 30 seconds?) when magnetic interference is preventing compass measurements, and the device is in inertial-only mode.

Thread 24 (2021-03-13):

Checkpoints using gpx, xml

kevinrocksman, 2021-03-13:
I believe that this device could be used to upload a flight path to going from checkpoint to checkpoint. This could be useful for long cross country flights.

Something along the lines of a specific file name existing on the sdcard, if that file exists when one of the dip switches are switched it will activate the path starting at point one. Maybe if you had to turn the device off it would start back at the "nearest checkpoint "(the one that you are currently at).

blinken, 2021-03-16:
Great idea. Easy enough to do once the web interface is done.

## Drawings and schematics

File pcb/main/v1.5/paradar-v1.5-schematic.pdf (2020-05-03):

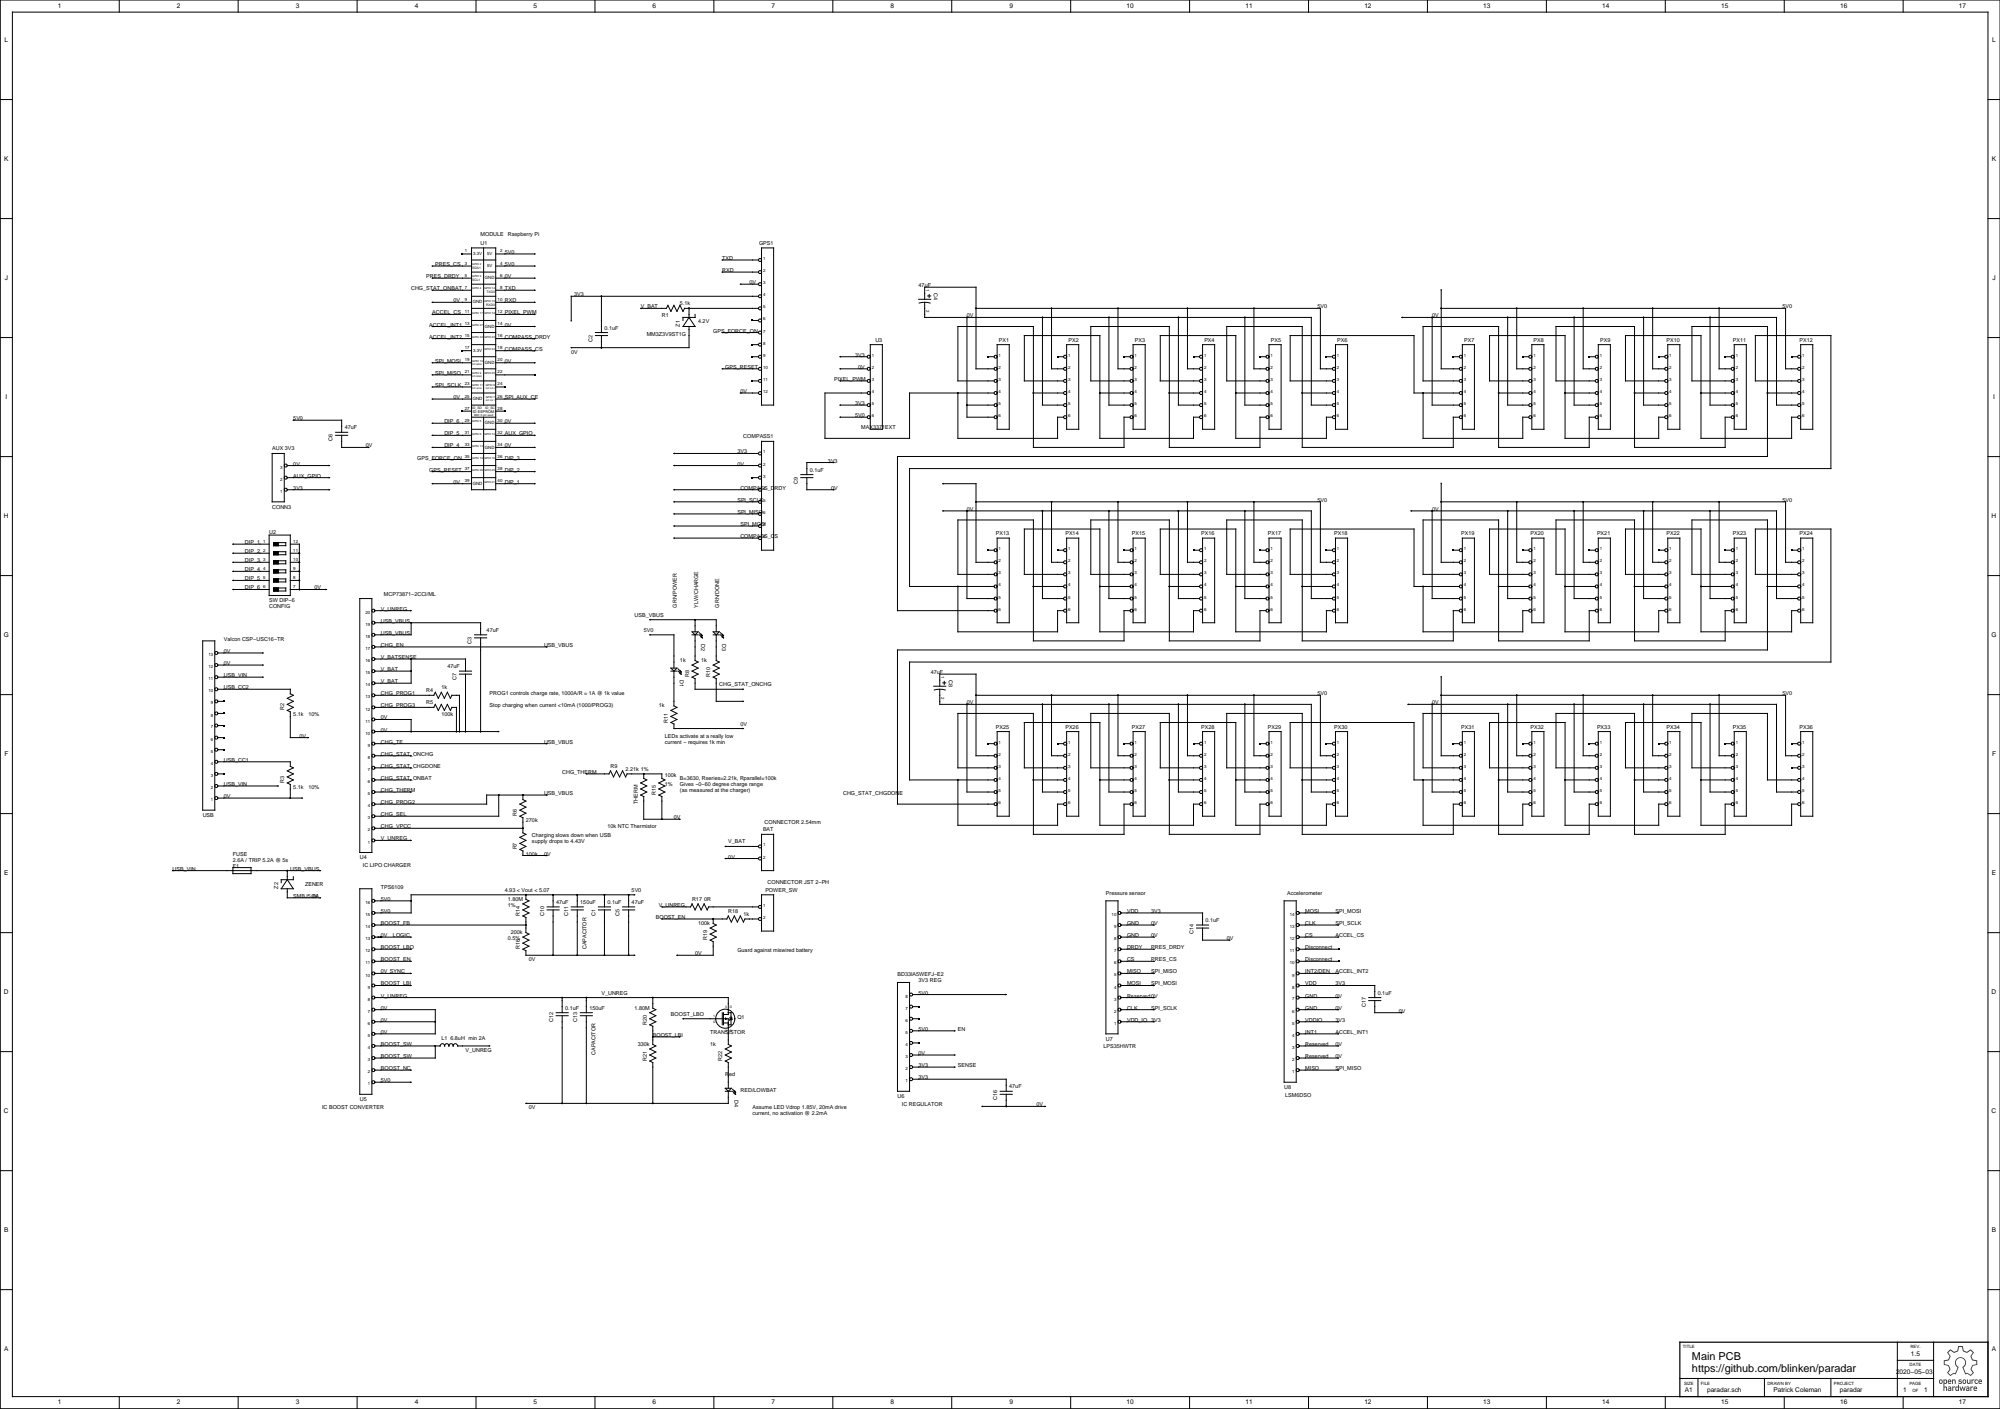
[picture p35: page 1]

SDA1

SCL1

TXD0

RXD0

SPI MOSI | | 20 GND

SPI MISO

SPI SCLK | SPI CE 0

SPI CE 1

ID EEPROM
DNC if not used
30 GND

PROG1 controls charge rate, 1000A/R = 1A @ 1k value

Stop charging when current <10mA (1000/PROG3)

LEDs activate at a really low
current − requires 1k min

B=3630, Rseries=2.21k, Rparallel=100k
Gives ~0−60 degree charge range
(as measured at the charger)

Charging slows down when USB
supply drops to 4.43V

Guard against miswired battery 0V

Assume LED Vdrop 1.85V, 20mA drive
current, no activation @ 2.2mA

TITLE
Main PCB
https://github.com/blinken/paradar

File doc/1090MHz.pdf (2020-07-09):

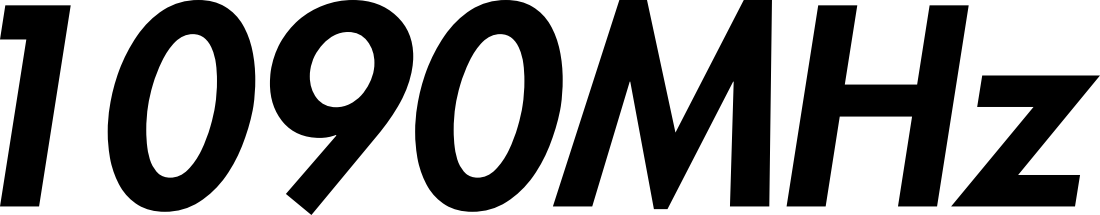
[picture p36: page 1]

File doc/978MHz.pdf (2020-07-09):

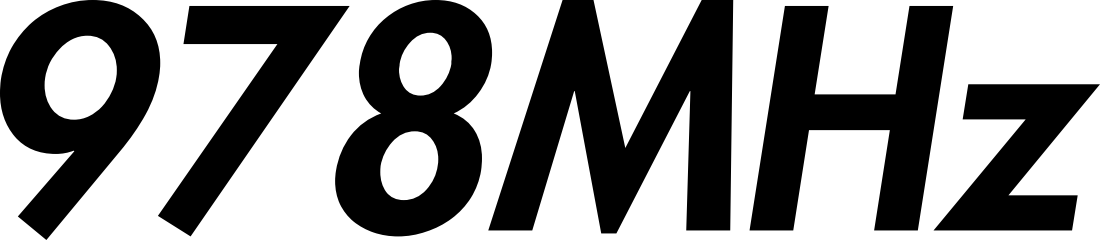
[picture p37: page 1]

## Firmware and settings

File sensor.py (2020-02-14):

#!/usr/bin/env python3
#
# This file is part of paradar (https://github.com/blinken/paradar).
#
# Copyright (C) 2020 Patrick Coleman
#
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
import io
import struct
import math
import pynmea2
import serial
import signal
import socket
import sys
import threading
import time
import traceback
import RPi.GPIO as GPIO

from datetime import datetime, timedelta
from geographiclib.geodesic import Geodesic
from spidev import SpiDev

import board
import neopixel

GPIO.setmode(GPIO.BCM)

# Clean up GPIOs on exit
def signal_handler(sig, frame):
  GPIO.cleanup()
  sys.exit(0)
signal.signal(signal.SIGINT, signal_handler)

class Compass:
  _REG_POLL = 0x00
  _REG_CONTINUOUS_MEASUREMENT_MODE = 0x01
  _REG_CYCLE_COUNT_X_H = 0x04
  _REG_CYCLE_COUNT_X_L = 0x05
  _REG_TMRC = 0x0b
  _REG_RESULT = 0x24

  _READ_OFFSET = 0x80

  _SPI_FREQ = 500000 # We won't actually achieve this because time.sleep only has a resolution down to ~1ms
  _INSTRUCTION_SLEEP = 1.0/_SPI_FREQ

  _RES_DRDY = 0x80

  _GPIO_CHIP_SELECT = 24
  _GPIO_DRDY = 23
  _CLK = 11
  _MISO = 9
  _MOSI = 10


  def __init__(self):
    GPIO.setup(self._GPIO_CHIP_SELECT, GPIO.OUT)
    GPIO.setup(self._MISO, GPIO.IN)
    GPIO.setup(self._MOSI, GPIO.OUT)
    GPIO.setup(self._CLK, GPIO.OUT)

    GPIO.output(self._GPIO_CHIP_SELECT, GPIO.HIGH)

    GPIO.setup(self._GPIO_DRDY, GPIO.IN)

    self._clk_idle()

    #self.spi = SpiDev()
    #self.spi.open(0, 0)
    #self.spi.max_speed_hz = self._SPI_FREQ
    #self.spi.cshigh = False

    # Clear REG_POLL & reg_cmm
    #self._write(self._REG_POLL, 0x00)
    #self._write(self._REG_CONTINUOUS_MEASUREMENT_MODE, 0x00)
    self._soft_write_bytes([self._REG_POLL, 0x00])
    self._soft_write_bytes([self._REG_CONTINUOUS_MEASUREMENT_MODE, 0x00])

    # Set cycle count
    self._set_cycle_count()

    # Activate continuous measurement
    self._soft_write_bytes([self._REG_TMRC, 0x92])
    self._soft_write_bytes([self._REG_CONTINUOUS_MEASUREMENT_MODE, 0x79])
    #self._write(self._REG_TMRC, 0x96)
    #self._write(self._REG_CONTINUOUS_MEASUREMENT_MODE, 0x79)

    print(hex(self._soft_read_reg(0x8b)))
    print(hex(self._soft_read_reg(0x81)))
    #print(hex(self._read(0x8b)))
    #print(hex(self._read(0x81)))

    #self._debug()

    self.update()

  def _raw_cs(self, state):
    if state:
      GPIO.output(self._GPIO_CHIP_SELECT, GPIO.LOW)
    else:
      GPIO.output(self._GPIO_CHIP_SELECT, GPIO.HIGH)

  def _soft_write_bytes(self, w_bytes):
    self._raw_cs(True)
    for b in w_bytes:
      self._soft_write(b, 8)
    self._raw_cs(False)

  def _soft_read_reg(self, reg):
    self._raw_cs(True)
    self._soft_write(reg, 8)
    result = self._soft_read(8)
    self._raw_cs(False)

    return result

  def _debug(self):
    print("Data ready: " + str(GPIO.input(self._GPIO_DRDY)))
    print("Clearing _REG_POLL & reg_cmm")
    print("_REG_POLL: " + hex(self._write(self._REG_POLL, 0x00) & self._RES_DRDY))
    print("reg_cmm: " + hex(self._write(self._REG_CONTINUOUS_MEASUREMENT_MODE, 0x00) & self._RES_DRDY))

    print("Setting cycle count")
    self._set_cycle_count()

    print("Setting up continuous measurement")
    print("_REG_TMRC: " + hex(self._write(self._REG_TMRC, 0x98) & self._RES_DRDY))
    print("reg_cmm: " + hex(self._write(self._REG_CONTINUOUS_MEASUREMENT_MODE, 0x71) & self._RES_DRDY))

  # Wrap a method that does something with the chip, activating the chip-select
  # before and after it is accessed.
  def chip_select(function):
    def decorator(*args):
      time.sleep(Compass._INSTRUCTION_SLEEP)
      GPIO.output(Compass._GPIO_CHIP_SELECT, GPIO.LOW)
      time.sleep(Compass._INSTRUCTION_SLEEP)

      result = function(*args)

      time.sleep(Compass._INSTRUCTION_SLEEP)
      GPIO.output(Compass._GPIO_CHIP_SELECT, GPIO.HIGH)
      time.sleep(Compass._INSTRUCTION_SLEEP)

      return result

    return decorator

  def _write(self, reg, value):
    self._raw_cs(True)
    result = self.spi.xfer2([reg, value])[0]
    self._raw_cs(False)
    return result

  def _read(self, reg):
    self._raw_cs(True)
    result = self.spi.xfer2([reg | self._READ_OFFSET, 0x00])[1]
    self._raw_cs(False)
    return result

  def _clk_active(self):
    GPIO.output(self._CLK, GPIO.HIGH)

  def _clk_idle(self):
    GPIO.output(self._CLK, GPIO.LOW)

  def _soft_write(self, data, numBits):
    ''' Sends 1 Byte or less of data'''
    data <<= (8 - numBits)
    retVal = 0

    self._clk_idle()
    time.sleep(self._INSTRUCTION_SLEEP)

    for bit in range(numBits):
      # Set RPi's output bit high or low depending on highest bit of data field
      if data & 0x80:
        GPIO.output(self._MOSI, GPIO.HIGH)
      else:
        GPIO.output(self._MOSI, GPIO.LOW)

      self._clk_active()
      time.sleep(self._INSTRUCTION_SLEEP)

      # Read 1 data bit in
      if GPIO.input(self._MISO):
        retVal |= 0x1

      self._clk_idle()

      # Advance input & data to next bit
      retVal <<= 1
      data <<= 1

    # Divide by two to drop the NULL bit
    retVal >>= 1
    return retVal

  def _soft_read(self, numBits):
    '''Receives arbitrary number of bits'''
    retVal = 0

    GPIO.output(self._MOSI, GPIO.HIGH)
    self._clk_idle()

    for bit in range(numBits):
      # Pulse clock pin
      self._clk_active()
      time.sleep(self._INSTRUCTION_SLEEP)

      # Read 1 data bit in
      if GPIO.input(self._MISO):
        retVal |= 0x1

      self._clk_idle()

      # Advance input to next bit
      retVal <<= 1

    # Divide by two to drop the NULL bit
    retVal >>= 1
    return (retVal)

  def _set_cycle_count(self):
    cycle_count = 0xc8
    # Set the cycle count the same for x/y/z
    self._soft_write_bytes([
      0x04,
      0x00, cycle_count,
      0x00, cycle_count,
      0x00, cycle_count,
    ])

  def _unpack_measurement(self, l):
    x = bytearray(l + [0x00])
    return (struct.unpack(">i", x)[0] >>1)/46603.0

  def get_raw_measurements(self):
    # From the design guide --
    # Normally it is only necessary to send "A4", since the register value automatically
    # increments on the clock cycles such that after sending "A4" all 3 bytes for the X axis
    # measurement would be clocked out, then the 3 bytes for the Y axis measurement, then the 3
    # bytes for the Z axis measurement. After these 9 bytes have been clocked out, the subsequent
    # output data has no relevance.

    #self.spi.xfer2([self._REG_RESULT | self._READ_OFFSET])
    #results = self.spi.readbytes(9)
    self._raw_cs(True)
    self._soft_write(0xa4, 8)
    results = []
    for i in range(9):
      res = self._soft_read(8)
      results = results + [res]
    self._raw_cs(False)

    x = self._unpack_measurement(results[:3])
    y = self._unpack_measurement(results[3:6])
    z = self._unpack_measurement(results[6:9])

    return (x, y, z)

  def get_azimuth(self):
    return self._azimuth

  def update(self):
    while GPIO.input(self._GPIO_DRDY) == 0:
      time.sleep(self._INSTRUCTION_SLEEP) # todo, convert to wait_for_edge

    x, y, z = self.get_raw_measurements()
    self._azimuth = (180/math.pi * math.atan2(y, x)) % 360

    #print(self._azimuth)
    return self._azimuth

  def to_string(self):
    return str(round(self._azimuth, 1))

class GPS:
  DEVICE = "/dev/ttyAMA0"
  SPEED = 9600
  TIMEOUT = 3.0

  def __init__(self):
    self._raw_port = serial.Serial(self.DEVICE, baudrate=self.SPEED, timeout=self.TIMEOUT)
    self.port = io.TextIOWrapper(io.BufferedRWPair(self._raw_port, self._raw_port), encoding='ascii')

    self.latitude = 0.0
    self.longitude = 0.0
    self.updated = datetime(1970,1,1)

  def __del__(self):
    self._raw_port.close()

  def track_gps(self):
    while True:
      try:
        line = self.port.readline().strip()
        if not line or line[0] != '$':
          # Serial can be very noisy. Silently ignore non-ASCII characters with
          # UnicodeDecodeError below
          continue

        msg = pynmea2.parse(line)
        if msg.sentence_type == 'GGA':
          self.latitude = msg.latitude
          self.longitude = msg.longitude
        elif msg.sentence_type == 'RMC':
          self.updated = msg.datetime
        else:
          continue

      except UnicodeDecodeError:
        pass
      except serial.SerialException as e:
        print("Serial exception (" + str(e) + "), resetting port")

        if self._raw_port:
          self._raw_port.close()
          self._raw_port = serial.Serial(self.DEVICE, baudrate=self.SPEED, timeout=self.TIMEOUT)
          self.port = io.TextIOWrapper(io.BufferedRWPair(self._raw_port, self._raw_port), encoding='ascii')
      except pynmea2.nmea.ChecksumError:
        pass
      except pynmea2.nmea.ParseError:
        print("GPS: unparseable string '" + line + "'")
      except Exception as e:
        print("Unknown exception parsing NMEA - " + str(e))
        traceback.print_exc()
        time.sleep(0.2)

  def is_fresh(self):
    print("GPS fix is " + str(datetime.today() - self.updated) + " old")
    return (datetime.today() - self.updated) < timedelta(minutes=2)

class Display:
  _GPIO_DATA = board.D18
  _PIXEL_COUNT = 36
  _PIXEL_ANGLE_OFFSET = 0

  _DEGREES_PER_PIXEL = 360.0/_PIXEL_COUNT

  _COLOUR_COMPASS_NORTH = (0, 0, 255) # blue
  _COLOUR_COMPASS_EAST = (0, 255, 0) # green
  _COLOUR_COMPASS_WEST = (255, 255, 255) # white

  _BRIGHTNESS = 0.3

  def __init__(self):
    self.pixels = neopixel.NeoPixel(board.D18, self._PIXEL_COUNT, auto_write=False, bpp=3, brightness=self._BRIGHTNESS)
    self.off()
    self._refresh()

  def _refresh(self):
    self.pixels.show()

  def _pixel_for_bearing(self, bearing):
    uncorrected_pixel = (self._PIXEL_COUNT - 1) + int(bearing/self._DEGREES_PER_PIXEL)

    return (uncorrected_pixel + self._PIXEL_ANGLE_OFFSET) % (self._PIXEL_COUNT - 1)

  def _calculate_bearing(ac_value, compass_angle, gps):
    result = Geodesic.WGS84.Inverse(ac_value[1], ac_value[2], gps.latitude, gps.longitude)

    bearing = ((result['azi1']+180) + compass_angle) % 360
    return (bearing, result['s12'])

  def off(self):
    for i in range(self._PIXEL_COUNT):
      self.pixels[i] = (0, 0, 0)

  # Refresh the display with the value of self.pixels
  def update(self, compass, gps, aircraft_list):
    self.off()

    # Indicate compass north
    self.pixels[self._pixel_for_bearing(compass.get_azimuth())] = self._COLOUR_COMPASS_NORTH
    #self.pixels[self._pixel_for_bearing(compass.get_azimuth()+90)] = self._COLOUR_COMPASS_EAST
    #self.pixels[self._pixel_for_bearing(compass.get_azimuth()-90)] = self._COLOUR_COMPASS_WEST

    vectors = [ Display._calculate_bearing(value, compass.get_azimuth(), gps) for value in list(aircraft_list.values()) ]
    # Order the list of vectors to aircraft by distance, descending - so closer
    # aircraft are displayed over farther ones.
    vectors.sort(key=lambda x: x[1], reverse=True)

    for ac_bearing, ac_distance in vectors:
      if ac_distance > 100000.0:
        # squelch aircraft too distant
        continue

      next_pixel = self._pixel_for_bearing(ac_bearing)
      next_brightness = int(max(0, min(255, ((15000-ac_distance)*255/10000.0))))

      self.pixels[next_pixel] = (next_brightness, 10, 00)

    self._refresh()

class Aircraft:
  positions = {}

  def __init__(self):
    self.sock = socket.socket(socket.AF_INET, socket.SOCK_STREAM)
    #self.sock.connect(("127.0.0.1", 30003))

  def _parse(self, line):
    try:
      # ['MSG', '3', '1', '1', '3C66B3', '1', '2019/11/26', '16:37:53.908', '2019/11/26', '16:37:53.950', '', '8650', '', '', '51.64426', '0.10422', '', '', '', '', '', '0\n']
      (msg_class, msg_type, _, _, ac_id, _, ac_date, ac_time, _, _, _, _, _, _, ac_lat, ac_lon, _) = line.split(",", 16)

      if msg_class != "MSG" or msg_type != "3":
        return None

      ac_datetime = datetime.strptime(ac_date + " " + ac_time, "%Y/%m/%d %H:%M:%S.%f")
      ac_lat = float(ac_lat)
      ac_lon = float(ac_lon)
    except ValueError:
      print("Bad coordinate string: '{}'".format(line))
      return None

    return {ac_id: (ac_datetime, ac_lat, ac_lon)}

  def track_aircraft(self):
    while True:
      ac_result = self._parse(self.sock.makefile(buffering=1024000).readline().strip())

      if ac_result == None:
        continue

      Aircraft.positions.update(ac_result)

      # Clean up values older than 300 seconds
      for ac_id, value in Aircraft.positions.copy().items():
        if (datetime.now() - value[0]) > timedelta(minutes=1):
          print("Removing expired aircraft " + ac_id)
          del Aircraft.positions[ac_id]

ac = Aircraft()
t_ac = threading.Thread(target=ac.track_aircraft, args=(), daemon=True)
t_ac.start()

gps = GPS()
t_gps = threading.Thread(target=gps.track_gps, args=(), daemon=True)
t_gps.start()

compass = Compass()
display = Display()

while True:
  if not gps.is_fresh():
    print("Warning: GPS position is not up-to-date")

  t_start = time.time()
  cycle_length = 100

  for i in range(cycle_length):
    compass.update()
    display.update(compass, gps, Aircraft.positions)

  t_end = time.time()
  refresh_rate = cycle_length*1.0/(t_end - t_start)
  print("Refresh rate: " + str(round(refresh_rate, 2)) + "Hz")

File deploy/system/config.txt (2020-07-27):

# Disable the rainbow splash screen
disable_splash=1

# Ensure the first uart is enabled, and bluetooth is disabled. Activate the SPI
# kernel drivers and overclock the SD card to 100MHz.
# The application sets up the SPI pins to the required function, so no need to
# do this in a dtoverlay.
#dtdebug=on
dtoverlay=uart0
dtoverlay=disable-bt
dtparam=spi=on,spi_dma4,sd_overclock=100,act_led_trigger=heartbeat

# Drive the pixel pin low to prevent noise/random lights
gpio=18=a5

# BCM24 - compass CS
# BCM2 - pressure CS
# BCM17 - accel CS
# Drive all the CS pins high
gpio=2=op,dh
gpio=24=op,dh
gpio=17=op,dh

# Set the bootloader delay to 0 seconds. The default is 1s if not specified.
boot_delay=0

# Make sure the core frequency is fixed to avoid issues with the UART
force_turbo=1

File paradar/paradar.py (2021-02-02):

#!/usr/bin/env python3
# -*- coding: utf-8 -*-
#
# This file is part of paradar (https://github.com/blinken/paradar).
#
# Copyright (C) 2020 Patrick Coleman
#
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
import cProfile
import signal
import sys
import threading
import time
import traceback
import os
import subprocess

from gpsd import NoFixError

try:
  from RPi import GPIO
except ImportError:
  from gpio_stub import GPIO

from aircraft import Aircraft
from gps import GPS
from compass import Compass
from display import Display
from config import Config
from gdl90 import GDL90

threads = {"main": threading.main_thread()}

# Print a stack trace when we receive SIGUSR1
def usr1_handler(sig, frame):
    """Print a stacktrace when we receive SIGUSR1, to enable debugging"""

    print("** SIGUSR1 received - printing tracebacks all threads\n")
    for t_id, t_frame in sys._current_frames().items():
      name = "unknown thread ({})".format(t_id)
      for t_name, t_obj in threads.items():
        if t_obj.ident == t_id:
          name = t_name
          break

      print ("=> {}".format(name))
      print(''.join(traceback.format_stack(t_frame)))
signal.signal(signal.SIGUSR1, usr1_handler)

# Clean up GPIOs on exit
def interrupt_handler(sig, frame):
  global ac

  # Make sure dump1090 exits cleanly
  ac.shutdown()

  GPIO.cleanup()
  sys.exit(0)
signal.signal(signal.SIGINT, interrupt_handler)

def get_system_temp():
  return int(open("/sys/class/thermal/thermal_zone0/temp", "r").read().strip())/1000.0

def get_system_flags():
  try:
    output = subprocess.run("/opt/vc/bin/vcgencmd get_throttled", shell=True, capture_output=True).stdout.decode("utf-8").strip()
  except Exception as e:
    print("main: failed to get output from vcgencmd: {}".format(str(e)))
    return ""

  prefix = "throttled=0x"
  if not output.startswith(prefix):
    print("main: unknown output from vcgencmd '{}'".format(output))
    return []

  output = output[len(prefix):]
  if len(output) % 2 == 1:
    # This is really annoying
    output = "0" + output

  b = bytes.fromhex(output)

  flags = []

  if b:
    if b[0] & 0x01:
      flags.append("under voltage detected")
    if b[0] & 0x02:
      flags.append("arm frequency capped")
    if b[0] & 0x04:
      flags.append("throttled")
    if b[0] & 0x08:
      flags.append("soft temp limit reached")

  if len(b) >= 3:
    # Historical observations
    if b[2] & 0x01:
      flags.append("(under voltage detected)")
    if b[2] & 0x02:
      flags.append("(arm frequency capped)")
    if b[2] & 0x04:
      flags.append("(throttled)")
    if b[2] & 0x08:
      flags.append("(soft temp limit reached)")

  return ", ".join(flags)

def startup_tasks():
  """System commands to run on service start"""
  print("main: running startup tasks")
  subprocess.run("/usr/bin/tvservice -o", shell=True, capture_output=True) # disable HDMI

os.nice(-5)

gps = GPS()

compass = Compass()
threads["compass"] = threading.Thread(target=compass.track_ahrs, args=(), daemon=True)
threads["compass"].start()

display = Display(gps, compass)

# Blocks until the GPS is ready
display.start()

os.nice(15)

ac = Aircraft(gps)
threads["aircraft"] = threading.Thread(target=ac.track_aircraft, args=(), daemon=True)
threads["aircraft"].start()

gdl90 = GDL90(gps, ac, compass)
threads["gdl90"] = threading.Thread(target=gdl90.transmit_gdl90, args=(), daemon=True)
threads["gdl90"].start()

startup_tasks()
delay = 20

while True:
  t_start = time.time()
  cycle_length = 500

  for i in range(cycle_length):
    display.update(Aircraft.positions)
    time.sleep(delay/1000.0)

  t_end = time.time()
  refresh_rate = cycle_length*1.0/(t_end - t_start)
  if refresh_rate > 20:
    delay += 1
  else:
    delay = max(0, delay-1)

  print("main: display refresh rate {:2.2f} Hz, tracking {} aircraft (alt squelch {}), gps {}".format(refresh_rate, len(Aircraft.positions), "on" if Config.flight_mode() else "off", gps.get_status_str()))

  try:
    print("main: system temperature is {}°C".format(get_system_temp()))
  except Exception as e:
    print("main: unable to read system temperature: {}".format(e))

  flags = get_system_flags()
  if flags:
    print("main: system flags: {}".format(flags))

  if Config.enable_978():
    # In regions where 978MHz exists, traffic may be advertised on either
    # 978MHz or 1090MHz
    if ac.freq == 1090:
      ac.set_freq(978)
    else:
      ac.set_freq(1090)
  else:
    ac.set_freq(1090)

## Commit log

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2020-02-03 fix inverted bearing calculation and calibrate against flightradar24
    [sensor.py]
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2020-02-03 gps, test and add error handling
    serial is very, very noisy. Deal with the effects of this and attempt to handle common serial corruption and errors.
    [sensor.py]
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2020-02-03 schematic, add internal power supply and other tweaks
    Improvements for board v1.2
    - Add USB-C connector, battery charger, boost converter for 5V, and 3V3
    LDO regulator. Power supply design is loosely based on Adafruit's
    PowerBoost 1000, with some modifications to design parameters. It's
    intended to supply at least 2A @ 5V0 from a LiPo battery pack
    (discharge down to 3.2V), with 500mA @ 3V3 supplied by a regulator
    off the 5V0 bus.
    - Battery charge rate is 1A, so the USB bus is expected to provide 3A.
    If it supplies less, battery charge rate will intelligently reduce.
    - Add power switch, controlling EN on the TPS61090 boost converter
    (battery charger stays enabled). Po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
    [plane-spotter.sch]
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2020-02-03 layout v1.2, as sent to production for prototype
    Remove some more slivers of polygon that are causing issues with
    production DRC.
    Add gerber files for prototype build.
    [plane-spotter.bottom.gbr, plane-spotter.bottommask.gbr, plane-spotter.bottompaste.gbr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]
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2020-02-13 pcb, add small board to change USB connectors 90 degrees
    The Pi Zero has two microUSB OTG connectors, and the one for data is
    inconveniently located in the middle of the board. There's no adapter
    that I can easily find that will take this around 90 degrees in the
    dimensions of the larger hat board (77x77mm) - so create a small PCB
    that connects to both microUSB ports and provides a type-A female socket
    facing the right direction - with enough space for a Noolec full-size
    SDR.
    The microUSB plug into the power socket on the RPi is not connected
    (except to ground) - it's just there for mechanical stability. I hoped
    to provide a breakout but it's really tight. Maybe in a future revision.
    There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
    [pizero-usb-rightangle.sch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]
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2020-02-14 layout v1.3, as built
    Final tweaks before I order an initial run of 40.
    - Reduce soldermask clearance to 50um to try and fix the solder
    bridging issues on the QFN packages.
    - Remove battery feedback status input to the RPi, saving two resistors
    - GPS zener to 0805 pad to suit the component better
    - FLARM header to the other side of the board
    - Update the name to ... paradar!
    - Change all SMD pad connections to thin traces to avoid board heat
    conduction issues when reflowing.
    - Change the USB connector to a sane one!
    - Add mounting holes for the Raspberry Pi Zero (well, one mounting
    hole ;)
    Extend the USB right angle board to maximise space for the SDR, and add
    a small via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
    [paradar.bottom.gbr, paradar.bottommask.gbr, paradar.bottompaste.gbr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]
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2020-02-16 paradar, clean up logging
    Make logging easier to read and fix a broken import in Display.
    Print the current GPS fix and number of tracked aircraft occasionally.
    [compass.py, display.py, gps.py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]
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2020-02-17 gps, rip out serial interface and replacewith gpsd
    Oh god, that GPS serial interface code. So janky, so unreliable. It
    didn't help that I didn't realise getty was running on the same serial
    line and just randomly injecting noise.
    It turns out gpsd is a thing: a lightweight daemon that holds the
    last-seen position from the GPS. It's also useful for Chrony, so the
    system has a reasonably accurate clock (the serial interface means it's
    not super-accurate, but it's within a second).
    Rip out all that nasty serial code and replace it with a tiny call to
    the gpsd python library.
    [aircraft.py, display.py, gps.py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]
2020-02-23 paradar, squash bugs & reliability
    - If dump1090 crashes, don't crash loop so fast
    - dump1090 expects frequencies in Hz, not Mhz
    - Catch a variety of errors thrown by the gpsd library gracefully
    - Attempt to optimise by not calculating aircraft bearings so often
    [aircraft.py, display.py, gps.py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]
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2020-02-24 case, final adjustments
    - Add hole on lid for USB-C
    - Fix second power switch support post, which got lost somehow
    - Shift power switch hole and supports slightly away from the edge, so
    the switch has room to fit around the screw post
    - Reduce SD card hole slightly and add a countersunk rim to enable the
    grommet to grab the edge more easily.
    [007-caselid-final-base.stl, 007-caselid-final-lid.stl, 007-caselid-final.blend]
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2020-02-24 paradar, improve imports and add Config class
    Add a Config class to allow lookups against the state of the
    user-configurable DIP switch. The mapping from GPIO (switch #) to
    function is held in one place, and the functions are expressed as
    static methods on the class.
    To facilitate testing of this kind of code, fix the module imports so
    they check whether we're actually running on a Pi. If not, don't import
    things that depend on that hardware. This won't let the program run but
    permits unit testing.
    [compass.py, config.py, display.py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]
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2020-02-25 case, improve lid geometry
    The lid was always a bit of a hack - I did the countersunk cutouts for
    the screws after the shell, which was a mistake. Rework the lid to
    simplify the geometry, which should hopefully make it more reliable to
    print.
    Also - shift the power switch posts even further south, and enlarge the
    screw posts to give more material to fit screws into. Remove the
    bevelling since it was adding a ton of complexity, but still bevel
    top/bottom exterior vertices so the device is nice to hold.
    [007-caselid-final-base.stl, 007-caselid-final-lid.stl]
2020-02-25 paradar, squash bugs from testing on hardware
    - Fix some python import issues
    - Make self-test sequence not blind me
    [aircraft.py, compass.py, config.py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]
2020-02-25 paradar, reduce squelch to 30km
    Reduce the aircraft we track at once to a 30km radius, to get a more
    responsive display.
    Fix some typos.
    [display.py, gps.py]
2020-02-25 paradar, improve bearing and distance calculation
    We currently use geographiclib.geodesic.Geodesic, which does a lot more
    than just calculate bearing and distance and is quite slow. Include a
    reference implementation of great-circle-bearing and haversine distance
    which performs better.
    Squash a couple of small bugs found during testing.
    Update the squelch and warning distances based on some research I found.
    [aircraft.py, display.py, gps.py]
2020-02-25 paradar, fix config DIP switches to match markings
    The DIP switches have "ON" marked when the Pi reads logic low. The
    ordering of options also needs to be reversed to match printed numbers.
    [config.py]
2020-02-25 paradar, verify and calibrate compass
    - Check compass direction against a map and set the offset (the compass
    module isn't soldered with its north matching board north)
    - Make the display a little prettier by only taking one compass reading
    for all updates - avoiding a race (causing some pixels to update
    before others) if the reading changes mid-update.
    [display.py]
2020-02-29 layout usb v1.1, adjust positioning and add alternative layout
    The v1.0 layout didn't fit, sadly. The current male connector positions
    are a little too high on the board. Bring them down by 2-3mm, and add
    vias to allow connection of hookup wire if the male connectors don't
    work out.
    Remove the power LED and resistor, it's not useful and we don't have a
    huge amount of space.
    Add an alternative version of the board that can live on the same panel
    - it has the female USB connector on the bottom to allow for a different
    stack of components in the case (PI zero much higher). This is a
    fallback if the current stack doesn't work.
    Remove the solder mask from the mounting vias.
    As-built gerbers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
    [pizero-usb-rightangle-b.bottom.gbr, pizero-usb-rightangle-b.bottommask.gbr, pizero-usb-rightangle-b.bottompaste.gbr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]
2020-03-01 layout v1.4, fix netlist errors
    Due to duplicate netnames on two signal pins on the MCP73871, the last
    run of PCBs didn't have two important pins connected. Fix the schematic,
    fix the PCB and make some other small tweaks to layout.
    Add another mounting hole near the top of the board so the board can sit
    in an SMD reflow oven without falling over.
    Remove the soldermask from all the mounting holes.
    [paradar.sch]
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2020-03-07 paradar gdl90, add start of a class
    First pass at a class to generate GDL90 messages. It seems to be able to
    assemble a message and generate a correct checksum (from one test case).
    [gdl90.py]
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2020-03-08 case, increase dimensions and add cutaways for USB PCB
    - Increase dimensions by 1mm to allow more breathing room/manufacturing
    tolerances.
    - Shift the SDR +3mm in the X direction, to give the USB connectors
    more space.
    - Cut away the screw hole supports on the bottom edge to allow the SDR
    to fit
    - Shorten the SDR mounting post to let the USB board fit in place.
    [007-caselid-final-base.stl, 007-caselid-final-lid.stl]
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2020-03-08 paradar gdl90, fix typos and initial testing with skydemon
    Happily, SkyDemon detects the device and receives GPS data! It is not yet
    showing traffic, possibly because we need altitude information.
    Fix a ton of typos and add some better error handling.
    [gdl90.py, paradar.py]
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2020-03-08 paradar gdl90, working integration with skydemon
    Build on previous work and extend the ADS-B decoding and GDL-90 generation to
    get minimum functionality required for SkyDemon.
    - My position, track, speed and altitude are shown
    - Detected aircraft show speed, altitude, position, track
    Todo:
    - Detect and forward correct airframe type and callsign
    - Test compatibility with other apps (and iOS, which apparently doesn't like UDP broadcasts)
    [aircraft.py, display.py, gdl90.py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]
2020-03-09 paradar gdl90, normalise callsign and add EC
    Add the emitter category, which sets the right icon in SkyDemon (jet,
    helicopter, etc). Normalise the callsign to strip _ characters and replace them
    with spaces.
    [aircraft.py, gdl90.py]
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2020-03-17 Revert "paradar gps, stub out most methods for testing"
    This reverts commit d4c7808e2f0d62f4c12264b7e2f2913a623ef48f - main board is
    now working so I can go back to testing properly.
    [gps.py, paradar.py]
2020-03-17 paradar gdl90, fix bugs from insitu testing
    Testing with an actual GPS uncovered some assumptions I made in my test
    harness. Fix some typos and bugs.
    [gdl90.py]
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2020-03-21 paradar display, be more defensive when accessing shared data
    Don't crash with a runtime error if the aircraft_list gets updated while we're
    also modifying it - just skip a display update.
    [display.py]
2020-03-21 paradar, track_home bugs and improve alt squelch
    - Remove the display test feature, and use that dip switch to enable and
    disable altitude squelch. Reduce the squelch limit to 10,000 ft
    - Fix some bugs with track_home - it was never properly updated to the new
    aircraft data structure
    - When we're close to home, change the home LED from green to a lighter teal
    - When we're _on top_ of home, assume a bearing of 180* (due south) to avoid
    display weirdness
    [config.py, display.py, paradar.py]
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2020-03-22 paradar display, always show nearby home location as due south
    GPS drift means that trying to indicate a home location closer than 10m away
    just results in the display flickering and moving around a lot. Clamp the home
    bearing to 180 when we're within 10m.
    [display.py]
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2020-03-25 layout v1.5, initial changes to the schematic
    Update the schematic to make some small changes based on the assembly
    experience with v1.4.
    - Remove the SPI header and 5v header. I'll expose some of these pins
    as vias directly on the PCB, where space allows.
    - Re-value all the 22uF caps to be 47uF caps - these are the same size
    and price
    - Remove one of the LED caps, as it doesn't fit under the board next to
    the SDR.
    - Add an accelerometer and a pressure sensor. This is high risk... but
    in the worst case, those components don't work. The rest of the board
    is tested.
    - Update the battery connector to be a standard 2.54mm header, because
    that's the connectors the batterie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
    [paradar.sch]
2020-03-26 layout v1.5, update pcb
    Add the two new sensors to the PCB on the SPI bus, and remove
    unnecessary headers to save space. Remove the FLARM header.
    Relocate capacitors and the 3v3 regulator that collide with the SDR
    during assembly - tuck them just under the rpi, they should be
    low-profile enough.
    Change the battery connector to match the connectors supplied with the
    batteries, so I don't have to change them.
    Add soldermask over the mounting holes where the PCB hits the SDR (the
    lower half). Tidy up the soldermask a little bit and increase copper
    clearance in tight areas.
    Remove copper through-hole plating on the USB connector mounting holes
    to improve manufacturing reliability.
    Add a BOM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
    [20200325-paradar-v1.5-pcbway-bom.xlsx, W40754ASJ32-32sets-20200325-paradar-v1.5-pcbway-bom 2020-3-26.xlsx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]
2020-03-26 layout v1.5, as built
    - Make mounting holes plain holes - and exclude copper around to avoid
    shorts to the SDR case
    - Remove solderpaste on GPS and compass modules, so PCBWay can
    assemble the rest of the board (the cheap components), and I can do the
    rest.
    Re-render gerbers.
    [paradar.bottom.gbr, paradar.bottommask.gbr, paradar.bottompaste.gbr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]
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2020-03-26 layout v1.5, relocate thermistor away from power supply
    The battery charger gets incredibly hot when the battery is charging and
    the system is under load - I guess we're pushing it's max current limit
    @ 2-3 amps.
    To avoid it shutting of unnessarily, relocate the thermistor south so
    it's measuring the battery temperature, not the board temperature.
    The charge controller has a die thermal cutoff @ ~125 degrees, so it
    should handle its own thermal management ok. The thermistor is just
    there to protect the battery.
    [paradar.bottom.gbr, paradar.bottommask.gbr, paradar.bottompaste.gbr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]
2020-03-27 paradar gdl90, increase frequency, add unicast and improve error handling
    Some changes to improve reliability with SkyDemon.
    - Increase the frequency slightly above 1/second - to ensure we're meeting
    SkyDemon's minimum threshold before it displays an error to the user.
    - Add a ton of better error handling. In particular, log when the GPS doesn't
    have a fix, becuse we pass that on to SkyDemon and it will complain to the
    user.
    - Read the list of DHCP leases from tmpfs and send clients unicast messages
    rather than relying on broadcast. There's some reports that iPhones don't
    pass broadcast messages to apps properly, though I haven't tested. Fall back
    to broadcast if no clie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
    [gdl90.py]
2020-03-27 paradar display, fix an off-by-one error
    Pixel 36 would never be used, resulting in a bearing display error.
    [display.py]
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2020-03-28 paradar compass, smooth results with small moving average
    Stop compass readings jittering so much when there's noise - add a tiny moving
    average to the compass results. The aim here is to balance display
    responsiveness against jitter.
    [compass.py]
2020-03-28 paradar network, stop wifi restarting
    The wifi service monitors the GPIO pins for the DIP switches, and relies on the
    RPi's internal pullups to stop the switches cycling. This is fine until the
    main paradar service stops or crashes - in which case the signal handler calls
    GPIO.cleanup() and destroys the pullup configuration.
    Reconfigure pullups at the start of every network service loop, to make sure
    that when we read the GPIOs we have the correct values.
    [config.py, network.py]
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2020-03-28 paradar compass, fix moving average at 0/360 boundary
    Fix a dumb bug I introduced in 5781e1 - as the compass azimuth moves from
    0->360 (across the boundary) or back, the moving average would return
    (obviously) 180. This resulted in the display jumping around like a crazy thing
    across the boundary.
    Compute the moving averages on the raw compass measurements instead, which
    produces a much steadier result.
    [compass.py]
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2020-03-29 pcb, slight tweaks to right angle USB
    The type-b right angle USB board is the one we want.. but because I bet
    on the type a I don't have enough. So I need to order yet more board ... :'(
    It's an excuse to try panelising for the first time. This commit
    includes a tweaked rightangle board:
    - narrower shaft with more room for the SDR
    - USB connectors a little closer to the edge so they fit better
    - reroute some traces accordingly
    Changes are very minor so I didn't bump the version on the board.
    Add as-built individual boards, plus a panelised version.
    [combined.gko, pizero-usb-rightangle-b.bottom.gbr, pizero-usb-rightangle-b.bottommask.gbr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]
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2020-04-04 case, create STL files for new rapid assembly
    After some experimentation, I've decided to switch to the right-angle
    v1.1B USB PCB - ie. the board is reversed and up high. This means the
    board can clip neatly to the raspberry pi using a couple of USB-male
    connectors. This vastly speeds up assembly, but it needs some changes to
    the case.
    The USB board is slightly more separated from the raspberry pi than
    planned - 6mm instead of 3mm. This means the case needs to be larger in
    the Y dimension and slightly shorter in the X dimension.
    The board is also up much higher, so the lower cutaway from the
    bottom-right screw post doesn't help us. I experimented (009-*) with
    removing the bottom-right scre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
    [009-base.stl, 009-lid.stl, 010-base.stl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]
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2020-04-24 paradar adsb, catch a rare parsing error
    This can cause the device to hang after several days of operation - it seems
    adsb.velocity can sometimes return None. Handle this error gracefully.
    [aircraft.py]
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2020-07-18 compass, fix a silly calibration bug
    Calibration isn't correctly applied to the compass, I'm not sure why I
    haven't noticed.
    [compass.py]
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2020-07-27 rpi config, fix broken hardware SPI
    This was a point of confusion for me for a long time - the SPI drivers are
    enabled but return all zeros. It turns out one of the other dtoverlay
    parameters are conflicting with them. When all options are on the same line,
    with spi last, it works.
    [config.txt]
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2020-07-27 deploy, remove SD card tweaks and install gpsd clients
    Now the ordering in config.txt is fixed, the SD card tweaks seem to break the
    serial port (and so the GPS). I have no idea why. Remove these, I'm not sure
    they're giving us a performance improvement anyway.
    Install the gpsd clients for easier debugging. They pull in a lot of junk (X
    things) but I don't think it matters too much - they're pretty useful.
    [config.txt]
2020-07-27 system, fix mysterious SPI/serial issue and install GPIO util
    A mysterious GPIO issue has been dogging me since I started this project...
    enabling the UART would disable hardware SPI, and vice-versa. I worked around
    this originally by using bit-banged software SPI, but I need hardware SPI for
    the go sensor port (at least, I was reluctant to hack it again).
    Turns out... I was just failing to set the pin alternate function in my
    software. wtf. Anyway, I guess I now know a lot more about the device tree
    overlays, so deploy a sane config (and set the pixel pin low on boot to prevent
    noise causing random lights).
    raspi-gpio is a really useful tool, so add it to the software installed.
    [config.txt]
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2020-07-27 sensors, more tuning and integrate with python compass
    * Rip out the guts of compass.py and replace it with a call to the new go subsystem
    * Latched interrupts on the accelerometer, because we were missing triggers
    * Make the accelerometer constant time, because go was doing interesting
    things with all the threads (it was quite jittery). As long as we sample at
    a set rate and all that data ends up in the model, the rest should be fine.
    * Make the SPI bus rate an actual bus rate that the Pi supports (125Mhz / a multiple of 2).
    This works pretty well. It's remarkably immune to tilt and noise!
    Future work -
    * Considering batching accel. data in the fifo to reduce resource usage, an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
    [compass.py, paradar.py]
2020-07-27 system, update cmdline and config.txt for new kernel
    The new kernel hangs on boot with the frequency options. Set the root partition
    using PARTUUID to be sure (unsure if that was the root cause also).
    While I'm here, drive all three CS lines high during boot to avoid
    accelerometer lockups (my guess is that it's getting garbage during the boot
    process).
    [config.txt]
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2020-07-27 sensor, test, tune and integrate with the python
    This is looking really good now.
    * Use circular mean, rather than linear regression to calculate the offset
    between the gyro and the magnetometer. This is because linear regression
    doesn't work well on angles, when the angle wraps. A circular linear
    regression would be better - but keeping a track of the differences, rather
    than the absolute values, and calculating the mean on that is the next best
    thing for a non-statistician.
    * Updating the offset is expensive, so only do it so often. Similarly, drop
    10% of the buffer at a time, to reduce the expense copying data around. A
    buffer length @ 500 seems to work nicely.
    * I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
    [compass.py]
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2020-07-27 sensor, clean up branch and add compiled binary
    Most notably, fix a bug with float parsing in the altimeter.
    CHecking in a binary is a bit jank, but is a stopgap until there's a real build
    system.
    Note this has not been tested on boards without an IMU (ie. v1.4); it will
    likely need a better moving average or similar to reduce noise.
    [compass.py]
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2020-07-28 paradar, adjust nice values to support real-time sensors
    The sensor algorithms are really sensitive to being swapped off the CPU. Nice
    them to -20 to minimise craziness.
    Everything else should be niced to 0 in normal operation (nice is relative, and
    the process starts at -10).
    Limit the display refresh rate to 20Hz, to reduce Python's impact on the CPU.
    [compass.py, paradar.py]
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2020-07-28 compass, add pressure altitude
    Map the pressure altitude data through from the golang sensor binary, and
    export it via GDL90. Fix a metres/feet bug (gah) in ownship_geometric_altitude
    while I'm here.
    I'm not sure SkyDemon will actually use the pressure altitude...but we're sending it.
    Closes #9.
    Reduce the speed at which we send data to python, to ensure we never max out
    the CPU (even when running GDL90).
    [compass.py, gdl90.py, paradar.py]
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2021-01-30 gps, stop logging position to SD card
    This is a little problematic, and not necessary for debugging any more.
    Log more useful 2D/3D fix information instead.
    [gps.py, paradar.py]
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2021-01-30 compass, fix bug in altitude parsing
    If the altitude can't be parsed, it should be set to zero as expected by
    the GDL90 code.
    [compass.py]
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2021-02-02 paradar, bug fixes for flight mode
    From testing - fix some typos and crashes resulting from the previous
    refactoring. Improve the frequency at which the altimeter updates to
    make the flight-mode altimeter display more responsive. Lots of running up
    and down stairs to test this :)
    [display.py, paradar.py]
